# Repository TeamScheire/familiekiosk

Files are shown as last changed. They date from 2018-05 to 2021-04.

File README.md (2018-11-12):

# FamilieKiosk

__Disclaimer:__ De FamilieKiosk gebruikt [Telegram](https://web.telegram.org), en werkt dus slechts zolang de API van `Telegram` niet wijzigt en `Telegram` dit type gebruik toelaat. We doen ons best ondersteuning te bieden, maar kunnen hiertoe niet verplicht worden.

De `FamilieKiosk` is een simpele manier om verbonden zijn met familie vanop een afstand. Ideaal voor ouderen die wel op de hoogte willen zijn maar niet sociale media gebruiken.

The `FamilieKiosk` is a simple way to be connected with family from a distance. Ideal for elders who want to keep contact with family but don't use social media. 

# Nederlandse handleiding
De `FamilieKiosk` gebruikt een berichtenapp, [Telegram](https://web.telegram.org), om beelden, geluid en video door te sturen aan de FamilieKiosk-doos, welke aangesloten is op de TV. Zo zie je op de TV de berichten van je familieleden, ook al zit je niet zelf op sociale media. De FamilieKiosk-doos is wat men een IoT-device noemt. Dit betekent dat het connectie maakt met het internet via WiFi, en zo de gegevens bekomt om op de TV te tonen.

## Het toestel
Je kan zelf een FamilieKiosk bouwen, of er een bekomen via [ons](http://www.ingegno.be), via [dit formulier](https://docs.google.com/forms/d/e/1FAIpQLSeFdhst-ktf9GazYMNH7J7HR-cu2r0f12FVwysfPTQ48ZMgRQ/viewform?usp=pp_url) kan je ons gemakkelijk contacteren. Met onze handleiding ben je in een wip online berichten aan het delen! Enige technische kennis is wel vereist hiervoor!

1. Handleiding om een FamilieKiosk-doos aan je TV aan te sluiten: [FamilieKiosk Instellen](https://github.com/TeamScheire/familiekiosk/blob/master/handleiding/FamilieKiosk%20Instellen.md)
2. Handleiding om je FamilieKiosk helemaal zelf te maken: [DIY FamilieKiosk](https://github.com/TeamScheire/familiekiosk/blob/master/handleiding/DIY%20FamilieKiosk.md)

# English Manual
We are not yet active on the international market! Feel free to send us a translation.

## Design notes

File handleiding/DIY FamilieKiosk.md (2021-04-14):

# Maak zelf je eigen FamilieKiosk 

In deze handleiding leggen we uit hoe je een FamilieKiosk kunt bouwen. De Kiosk is een Raspberry Pi, welke via HDMI met je TV verbonden is.  Deze controleert output op de TV en draait een Telegram bot welke beelden, audio en video van je familieleden oppikt en afspeelt. 

## Set up Raspberry Pi
We gebruiken een Raspberry Pi 3B, welkje je bv in pakket kunt kopen bij [Velleman](https://www.velleman.eu/products/view/?id=435866)

Zo'n pakket komt met een lege microSD kaart, welke we moeten voorbereiden. We installeren er een linux OS op, zie de [software guide](https://www.raspberrypi.org/learning/software-guide/) voor meer info. Download de Raspbian Pi OS vanaf de [download pagina Raspbian](https://www.raspberrypi.org/software/operating-systems/). Gebruik de Raspberry Pi Imager, deze zal de laatste versie automatisch downloaden, waarna je een SD kaart kunt flashen. De FamilieKiosk is getest met versie.

* 2021-03-04-raspios-buster-armhf-full.zip

Eerder werden ook gebruikt:

* 2018-11-13-raspbian-stretch-full.zip
* 2020-05 raspbian

Met de Raspberry Pi Imager bekom je de laatste versie, wil je een oude versie, dan dien je de zip uit te pakken en bv [etcher.io/](https://etcher.io/) te gebruiken om de iso te flashen naar een SD kaart.

Je hebt nu je harde schijf voor je Raspberry Pi klaar. De Rasp zou moeten werken en je een linux desktop tonen. 

## Installeer nodige software op Raspberry Pi

Vooraleer je de familiekiosk zelf kan installeren moet je een aantal ondersteunende programmas installeren. Hiervoor moet je de Terminal gebruiken. Je kan de terminal opstarten met het zwarte icoon, in de menubalk links bovenaan.

Raspbian Terminal Icoon

Druk de commando's gegeven als `commando` om de nodige software te installeren. Eerst controleren we of python3 de standaard is. Voer commando uit: `python --version`. Indien het resultaat niet python 3.x versie is, maar python 2.x, dien je te switchen naar python3 via handleiding op [raspberry-valley](https://raspberry-valley.azurewebsites.net/Python-Default-Version/#switching-default-python-versions):

    python --version
    python3 --version

noteer de versies die je hebt op de RPi, bv 2.7 en 3.7, en voeg die toe aan de alternatieven (vervang XXX door de eertste twee digits van je versienummer):

    sudo update-alternatives --install /usr/bin/python python /usr/bin/python2.XXX 2
    sudo update-alternatives --install /usr/bin/python python /usr/bin/python3.XXX 1

Wijzig nu de default versie van python met

    sudo update-alternatives --config python

Test met `python --version`.

Hierna kun je de nodige software installeren

1. Beeldverwerking: `sudo apt-get install python-imaging-tk`
2. Button en buzzer support: `sudo apt-get install python-rpi.gpio python3-rpi.gpio`
3. Gstreamer voor audio en video: `sudo apt-get install python-gst-1.0 gstreamer1.0-tools`
4. telegram requirements: `sudo apt-get install libffi6 libffi-dev libssl-dev`
4. telegram python API: `sudo pip install python-telegram-bot --upgrade`
5. pexpect API: `sudo pip install pexpect`

Nu dien je de screensaver te disablen Doe dit via `sudo apt-get install xscreensaver`, dan uitzetten. Je moet eerst REBOOT doen, daarna via `Start menu->Voorkeuren->Schermbeveiliging` of indien Engelse versie via `Start menu -> Preferences -> Screensaver`. Je ziet daar een optie __Modus__, waar je uitschakelen kan kiezen als modus.

Vervolgens heb je de FamilieKiosk code nodig. Hiervoor maak je een kopie van onze code op een van volgende twee manieren. Via een clone van de code, als volgt in een terminal:

    cd
    git clone https://github.com/TeamScheire/familiekiosk.git 

of door de code te downloaden als zip van [https://github.com/TeamScheire/familiekiosk/](https://github.com/TeamScheire/familiekiosk/archive/master.zip), de zip te extracten, en op te slaan in `/home/pi`. Opgelet, hernoem de map als `familykiosk` na de unzip, dus bv indien naam map `familiekiosk-master` is:

    cd
    mv familiekiosk-master familiekiosk

Test de playback met volgende commando's in een terminal:

    omxplayer /home/pi/familiekiosk/src/video/dummy/testvideo.mp4
    gst-launch-1.0 playbin uri=file:///home/pi/familiekiosk/src/video/dummy/testvideo.mp4
    gst-launch-1.0 playbin uri=file:///home/pi/familiekiosk/src/voice/dummy/testvoice.ogg

Wanneer je foutmeldingen krijgt zoals "Pipeline doesn't want to pause." of "Pipeline wil niet pauseren" bij het uitvoeren van de laatste twee commando's, kijk dan zeker na of je het commando wel juist hebt ingevoerd. Let vooral op uri in plaats van url, het : symbool na file en de daarop volgende drie / symbolen.

## Autostart van de FamilieKiosk

Alle code is aanwezig op de Raspberry, nu moeten we nog zorgen dat het systeem automatisch de Kiosk start bij opstarten. We gebruiken `systemd` services om te autostarten.

De nodige scripts zijn aanwezig in de broncode in de map systemd, en moeten verplaatst worden naar de map `/lib/systemd/system/`. Doe dus

    sudo cp /home/pi/familiekiosk/systemd/fk_chatbot.service /lib/systemd/system/
    sudo cp /home/pi/familiekiosk/systemd/fk_tvbox.service /lib/systemd/system/

en wijzig de toegang naar 644 zodat ze kunnen opgestart worden door systemd:

    sudo chmod 644 /lib/systemd/system/fk_chatbot.service
    sudo chmod 644 /lib/systemd/system/fk_tvbox.service

Zorg nu dat deze services gekend zijn bij systemd door 1 na 1 volgende commando's uit te voeren:

    sudo systemctl daemon-reload
    sudo systemctl enable fk_chatbot.service
    sudo systemctl enable fk_tvbox.service
    sudo service fk_chatbot start
    sudo service fk_tvbox start

Op dit moment zullen deze services nog niet werken omdat je de chatbox nog niet geconfigureerd hebt! Geen zorgen, dat doen we straks.

Je kan indien gewenst de status opvragen van deze services, bv om Telegram chats te monitoren:

    systemctl status fk_chatbot.service

en voor de tvbox app:

    systemctl status fk_tvbox.service 

Indien gecrasht, herstarten kan via bv

    sudo service fk_chatbot start

of om de tvbox te herstarten:

    sudo service fk_tvbox start

Indien de tvbox niet automatisch start, zorg dan dat de Raspberry maar opstart na netwerkverbinding. Doe hiervoor:

    sudo raspi-config
    Select Option 3 (Boot Options).
    Select B2 (Wait for Network at Boot)

## Constructie van de FamilieKiosk-doos

De familiekiosk kan optioneel uitgebreid worden met drukknoppen en een buzzer. We voorzien code voor drukknop om vorige multimedia opnieuw te zien, om naar volgende multimedia te gaan, en om een antwoord/reactie te geven. Audio en video worden enkel voor een vast slot per dag getoond. De buzzer wordt gebruikt om aan te duiden dat dit slot start.

### Componenten
We gebruiken volgende componenten:

1. Een YL44 buzzer YL44 buzzer
2. Arcade drukknoppen. Bv van [arcadewinkel](https://www.bol.com/nl/p/arcadewinkel-concave-classic-arcade-drukknoppen-mixed/9200000079501752/) Drukknoppen
3. Jumper wires and connectors
4. lasercut enclosure

### Bekabeling
De Raspberry Pi 3B heeft aan de rechterkant pinnen waarop we componenten kunnen aansluiten. Deze hebben volgende nummering:

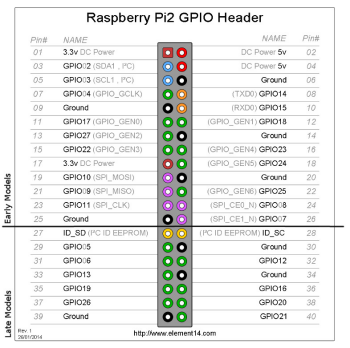
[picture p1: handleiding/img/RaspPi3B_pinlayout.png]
Rasp Pi pins


De rechterbovenhoek van deze figuur is ook de rechterbovenhoek van de Rasp Pi als je er van boven opkijkt. 

De bekabeling is als volgt: 

1. Buzzer GND pin verbinden we met een GND pin, bv pin# 05
2. Buzzer VCC pin verbinden we met de 3.3V pin, dus pin# 01
3. Buzzer I/O pin verbinden we met GPIO24, dus pin# 18
4. Alle drukknoppen zijn aan 1 kant verbonden met een GND pin, bv ook pin# 05
5. De andere kant van de drukknop gaat naar een GPIO pin. We gebruiken volgende: 
    1. Reply knop op GPIO18, dus pin# 12
    2. Next  knop op GPIO17, dus pin# 11
    3. Previous knop op GPIO23, dus pin# 16
    
Je hebt dus een stekker met 6 draden nodig. Schematisch is de bekabeling:

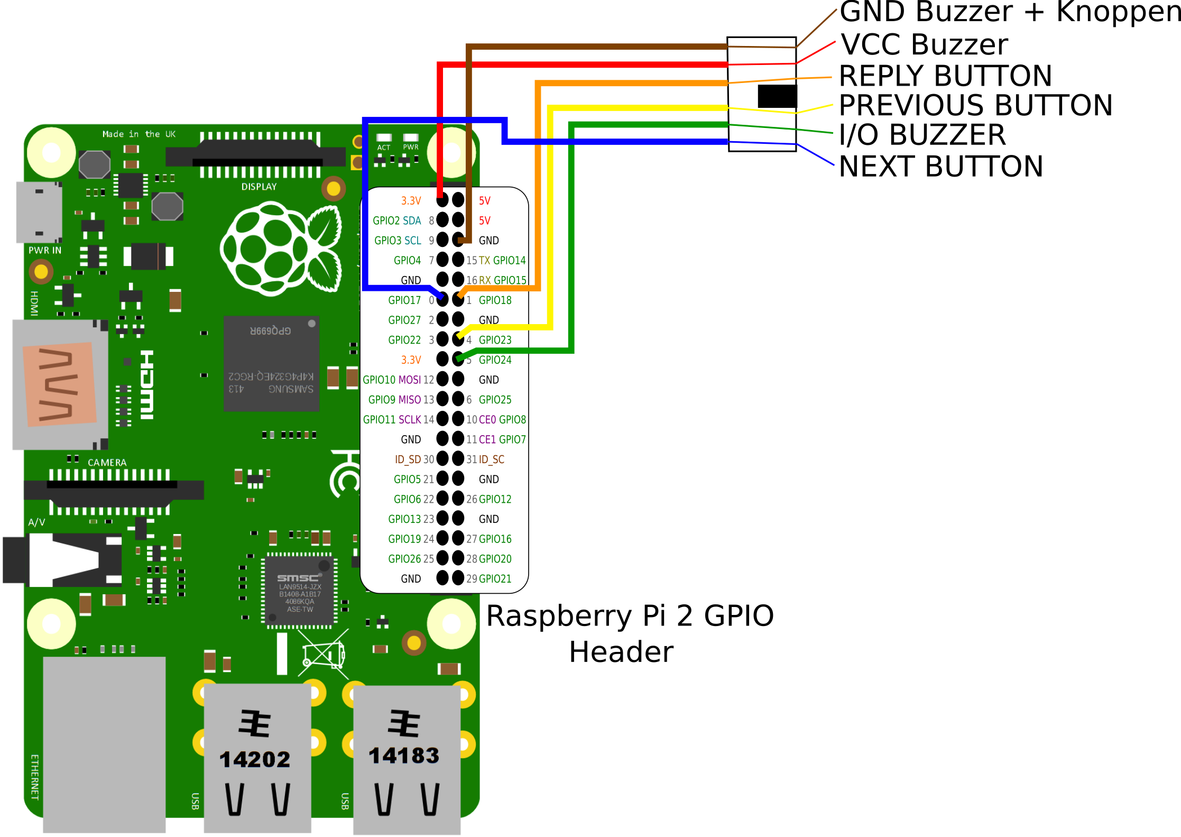
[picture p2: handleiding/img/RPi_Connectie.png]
Rasp Pi connecties


### De doos
Maak een mooie doos om de drukknoppen te bevatten, alsook de buzzer. Plaats de Raspberri Pi naast de TV, en maak een kabel naar je doos met 6 jumper wires in (GND, 3.3V, GPIO24/23/18/17). Maak kabel lang genoeg zodat doos op een gemakkelijke plek kan gezet worden.

Een voorbeeld gelasercutte doos is beschikbaar hieronder. Sla ze op als svg en pas aan naar eigen wensen:

Rasp Pi pins

In deze doos stop je de buzzer, en er is plaats voorzien voor 3 drukknoppen. De bedrading van de drukknoppen is als volgt:

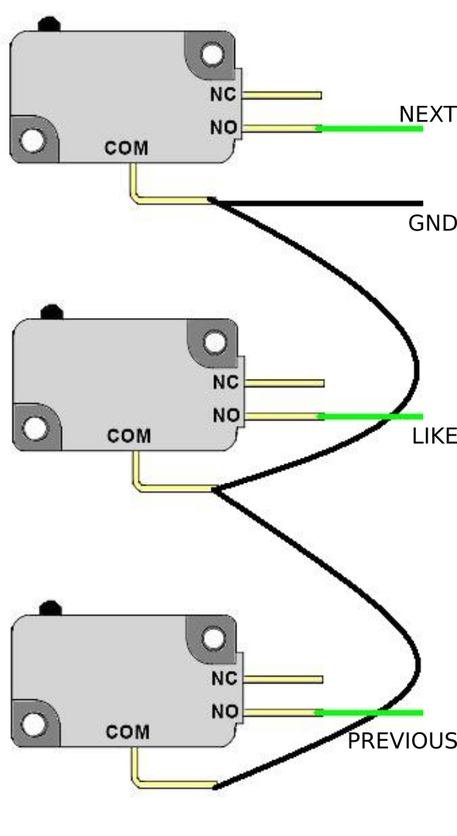
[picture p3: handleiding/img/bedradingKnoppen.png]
flexbox pushbuttons


## Instellen van de FamilieKiosk. 

De constructie en installatie is af. Dit is wat rechtstreeks van [Ingegno](http://ingegno.be/) kan bekomen worden. Nu dien je de FamilieKiosk in te stellen. Zie de [aparte installatie handleiding](https://github.com/TeamScheire/familiekiosk/blob/master/handleiding/FamilieKiosk%20Instellen.md).

## OUD: meer GPU geheugen

**Volgende is niet langer nodig voor recente Raspberry Pi OS!**

Op een Raspberry Pi 3B hebben we te weinig GPU processor kracht om video en audio te spelen met omxplayer. Om dit op te lossen doen we een wijziging in het bestand `/boot/config.txt` zoals beschreven in [hier](https://raspberrypi.stackexchange.com/questions/7716/omxplayer-doesnt-play-audio):
Open `/boot/config.txt` bv met `sudo thonny /boot/config.txt`, en voeg onderaan aan dit bestand toe:

    # sufficient gpu to run omxplayer
    gpu_mem=128

Reboot de Rasp om dit effect te laten nemen.

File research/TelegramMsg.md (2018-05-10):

# Telegram gebruiken om geluid door te sturen

We kijken eerst naar miflo project telegram backend. Dit gebruikt een ruby api voor Telegram op een server (bv een raspberry pi). Krijgt gekende berichten, parsed ze, en maakt ermee MQTT
messages naar de Arduino om zaken te doen.

Wij hebben nodig: telegram berichten opvolgen, is er geluid bij --> toelaten dat dat afgespeeld wordt. 

Onze ervaring is met python, dus kijken we naar een python api: https://python-telegram-bot.org/ 

Kunnen we hiermee geluidsfragmenten herkennen en dan afspelen via hdmi ?

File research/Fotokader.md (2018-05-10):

# Smart Fotokaders
Oorspronkelijk geen fotokaders gekocht want direct meer dan 100 eur en budget is beperkt. 
Dus, enkel info via onderzoek online. Uiteindelijk toch de Pix-Star 15 inch gekocht.

### NixPlay fotokader - 8 inch
https://www.gadgetgear.nl/2017/06/review-nixplay-cloud-frame-8-inch-digitale-fotolijst/
* Vraag is: hoe hackable is het? 
* testen?

### Frame XX 
https://www.fotolijst.info/contents/nl/d19_Digitale_Fotolijst_27_Inch.html
* Te groot
* Niet hackable
* Duur?

### Pix-Star 10.4 Inch Wi-Fi Cloud Digital Photo Frame FotoConnect XD
* Prijs is onder de 200 eur
* 10.4 in. (26.4 cm), 4:3 ratio, high-quality display with low consumption LED backlight. Manage the Frame from the Web and create a multi-frame account to remotely control up to 25 frames from 1 single web account, TOTALLY FREE.
* Send your photos by email via the 3G/Wi-Fi Network on your mobile phone, 4 GB memory (20,000 pictures), supports USB stick, SDHC and SDXC cards.Display size (diagonal): 15 inches(38.1 cm)
* Receive pictures directly on your Pix-Star frame from the Internet with its dedicated email address at NO EXTRA CHARGE
* Send pictures from your frame to individual or groups of email addresses directly from the frame
* Access more than 20 online providers and view pictures from web albums, including Picasa, Facebook, Flickr, Smugmug, and more and Receive daily updated weather forecasts for a selection of countries and cities

### Kodak Pulse digitale fotolijst
http://www.findmyorder.com/store/ekconseu/nl_NL/pd/ThemeID.3925900/PULSE_digitale_fotolijst__254%C2%A0cm_%2810_inch%29/productID.223116400
* Lijkt eenvoudig

### Braun digitale fotolijst voor Oma en Opa
https://www.fotolijst.info/contents/nl/p108_Braun_1010_Digitale_Fotolijst_WiFi.html
*  De fotolijst kan via Wifi met Internet verbonden worden en kan dan via de gratis Frameo App (Android en iOS) op afstand voorzien worden van nieuwe foto's.
*  Maak een foto met uw mobiele telefoon, selecteer de foto en stuur hem direct door naar de fotolijst.
* De digitale fotolijst stelt u één keer in op de Wifi. 
* één of meerder mobiele telefoons koppelen met de Digitale Fotolijst mogelijk via de Frameo App. 
* Meerdere telefoons kunnen verbonden worden, met één of meerder fotolijsten. De gehele familie kan dus de nieuwste foto's ontvangen. 
* De digitale fotolijst is geschikt voor microSD (max. 32 GB) geheugenkaarten. Eventuele foto's om de geheugenkaart kunnen worden overgezet naar de fotolijst, om deze snel te voorzien van enkele foto's. De microSD geheugenkaart kan als backup gebruikt worden, om alle foto's van de fotolijst veilig te stellen.

## Applicatie die werken op Tablets android
* https://www.familinq.com/ niet goedkoop, maar het lijkt mne wel een goede oplossing. Opslag in de cloud mogelijk 
* http://www.familylooped.com/about geen opslag in de cloud maar op tablet zelf, prijs niet gevonden ???

# DIY optie: 
WE PROBEREN DIT EERST, het lijkt het meest customizable en goedkoper

* Rasperry pi plus scherm, liefts TV want TV hebben ze en kennen ze
* Foto kanaal :-) 
* Applicatie Telegram
* Mogelijkheid om een audio bericht te sturen naar zender van de foto----Dit nog te bekijken hoe, want lijkt me nu niet eenvoudig met bakje van TV….
* Extra 
   * Audio berichten op bepaalde tijdstippen
   * Update van fotos op 1 tijdstip van de dag gekoppeld aan een leuke audio bericht 
   * TV? Webservice...post van de fotos

Nodig? Hdmi ingang
Usb microphone
Knop zoals die van de spelconsoles om voice message op te nemen

## DIY mogelijkheden voor fotos op TV te krijgen
Interessante dingen:

Op papier 1x maand https://neveo.io/#!/

Applicatie
https://mitene.us/en

Hoe een foto booth maken met raspberry pi
https://www.wikihow.com/Create-a-Photo-Booth-with-the-Raspberry-Pi

Flickr en raspberry pi
http://www.instructables.com/id/Internet-Photo-Frame/

Raspberry pi with lychee
https://www.pihomeserver.fr/en/2014/01/23/raspberry-pi-home-server-heberger-toutes-vos-photos/

Foto frame with raspberry pi beschreven onderaan Building a digital photo frame:

https://paulstamatiou.com/getting-started-raspberry-pi/ 

Met code voor Flickr
https://www.codeproject.com/Articles/1223258/Build-digital-photo-frame-with-a-Raspberry-Pi

https://dzone.com/articles/build-digital-photo-frame-with-a-raspberry-pi

GOOGLE PHOTO FRAME: Dit lijkt me compleet voor google fotos met applicatie photo frame van google (gevonden via https://hackaday.com/2018/03/05/shoot-and-forget-digital-photo-frame/ ), met heel wat code maar 
https://mrworf.github.io/photoframe/2018/02/26/setting-up-photoframe
https://github.com/mrworf/photoframe/blob/master/services/googlephotos.py

Good to Know:
Hoe fotos prive maken in flickr
https://www.wikihow.com/Make-Photos-Private-on-Flickr

Digital photo frame for people with dementia
http://sussexrokx.blogspot.be/2013/04/day-clock-for-people-with-dementia.html

Applicatie senior photo frame
https://play.google.com/store/apps/details?id=com.ellevsoft.seniorframe&hl=en_GB

## Gewoon foto kader kopen
15 inch, groot en heeft alles. Het zou goed zijn om te hebben en testen
https://shop.pix-star.com/products/pix-star-15-inch-cloud-frame-with-wi-fi-email-address-web-radio-and-more
In eu gevonden op amazon FR:
https://www.amazon.fr/Pix-Star-Num%C3%A9rique-FotoConnect-pouces-adresse/dp/B00MTWDG6W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

# Conclusie
* DIY kan maar problemen naar privacy (hackable, open sharen van foto’s) en replies op foto’s.  
* Daarom gekozen voor Pix-Star 15 inch fotokader om groot gebruiksgemak te hebben met beheerder van een account en emails naar een uniek adres om foto’s op fotokader te krijgen. Nu werk steken om de instellingen zo optimaal mogelijk te maken voor de noden van de zorginstelling
* Als DIY oplossing in backup is de beste optie gevonden:
https://mrworf.github.io/photoframe/2018/02/26/setting-up-photoframe
https://github.com/mrworf/photoframe/blob/master/services/googlephotos.py
Dit connecteert naar google photo’s, maar beperking is dat men enkel via queries foto’s toont of anders de laatste 5 recente foto’s

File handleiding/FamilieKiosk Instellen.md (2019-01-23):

__Disclaimer:__ De FamilieKiosk gebruikt [Telegram](https://web.telegram.org), en werkt dus slechts zolang de API van `Telegram` niet wijzigt en `Telegram` dit type gebruik toelaat. We doen ons best ondersteuning te bieden, maar kunnen hiertoe niet verplicht worden.

Je hebt een familiekiosk ontvangen. Dit omvat een doos met knoppen en een Raspberry Pi. Connecteer de delen als volgt:

1. Klik de kabel van de familiekiosk doos met knoppen aan de Raspberry Pi via de connector. 
2. Gebruik de HDMI kabel om de Raspberry Pi aan de TV te koppelen. 
3. Voor de eerste installatie moeten we nog enkele gegevens invullen. Hiertoe heb je een USB muis en toetsenbord nodig. Connecteer deze in de USB slots van de Raspberry Pi
4. De microUSB poort van de Raspberry Pi is om stroom te leveren. Plug de stroomkabel daar in, en plug deze in een stopcontact. __Opgelet: De TV moet aan zijn en de HDMI kabel ingeplugd voor je je Raspberry stroom heeft. Anders zul je geen beeld zien (Rasp start headless op).__

De Raspberry Pi start op, en toont onmiddelijk de Kiosk met de standaard foto. Om de Kiosk af te sluiten klik je op de __Linkermuis__ knop. Je bekomt dan de desktop: 

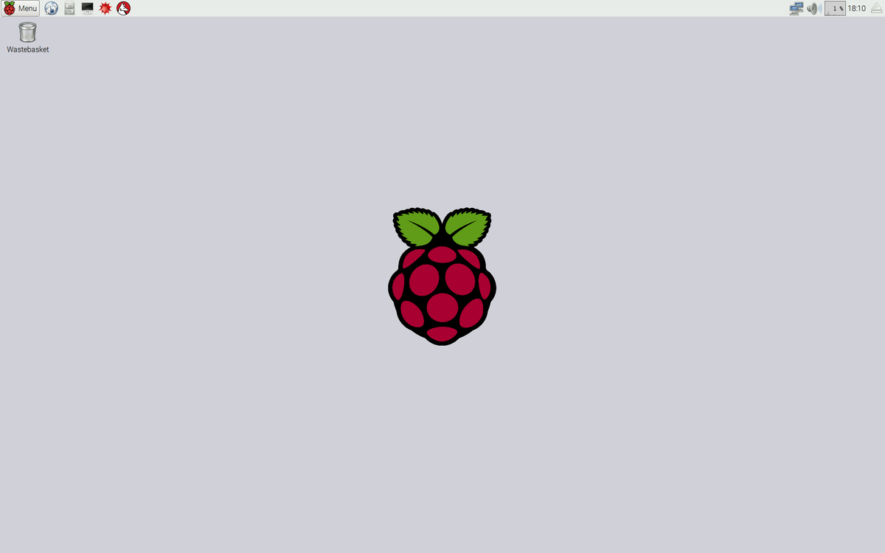
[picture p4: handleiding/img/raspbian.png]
Raspian


## Wifi Netwerk instellen

De Raspberry Pi beschikt over WiFi welke we gebruiken om met het internet te connecteren en nieuwe multimedia te bekomen voor de Kiosk. Je dient dus het netwerk in te stellen voor de locatie waar de familiekiosk opgezet wordt. Klik hiervoor in de rechterbovenhoek op het icoon van het netwerk, selecteer de SSID van je wifi netwerk, en geef je paswoord op. 

## Installeer Telegram, aamaken bot en configureren van de bot

De Kiosk werkt via een chatbot op [Telegram](https://telegram.org/) een chatapp met dezelfde functies als WhatsApp, maar met de mogelijkheid om er extra code voor te schrijven via bots. 

Net zoals bij Whatsapp, kan je via telegram groepsgesprekken hebben. De bot die je gaat maken, zal ook deel uitmaken van deze groep en de gedeelde foto's, video's en audioboodschappen automatisch kopiëren naar de familiekiosk.

1. Installeer [Telegram](https://telegram.org/) op je smartphone. 

Elke Familiekiosk moet zijn eigen _geheime_ chatbot hebben. Je gaat dus voor je eigen kiosk een chatbot aanmaken, deze configureren en toevoegen aan het groepsgesprek waar de rest van je familie in zit.

Bedenk een goede naam voor je bot, in deze handleiding gebruiken we ```MemePepeBot```. Wijzig deze door je eigen naam!

Het aanmaken en configureren van een bot gebeurt ook via Telegram door te praten met de chatbot ```@BotFather```.

Je kan dit doen via de telegram app op je smartphone, maar je kan ook via via [web.telegram.org](https://web.telegram.org) telegram openen. Voor de rest van deze handleiding gaan we er van uit dat je via de web-interface werkt.

2. Log in op [web.telegram.org](https://web.telegram.org)
3. Praat met ```@BotFather``` door te klikken op volgende link: [web.telegram.org/#/im?p=@BotFather ](https://web.telegram.org/#/im?p=@BotFather)
4. In het gesprek met ```@BotFather``` vraag je een nieuwe bot aan met volgend commando: ```/newbot``` De volledige conversatie ziet er ongeveer zo uit. Kies uiteraard een andere naam ;)

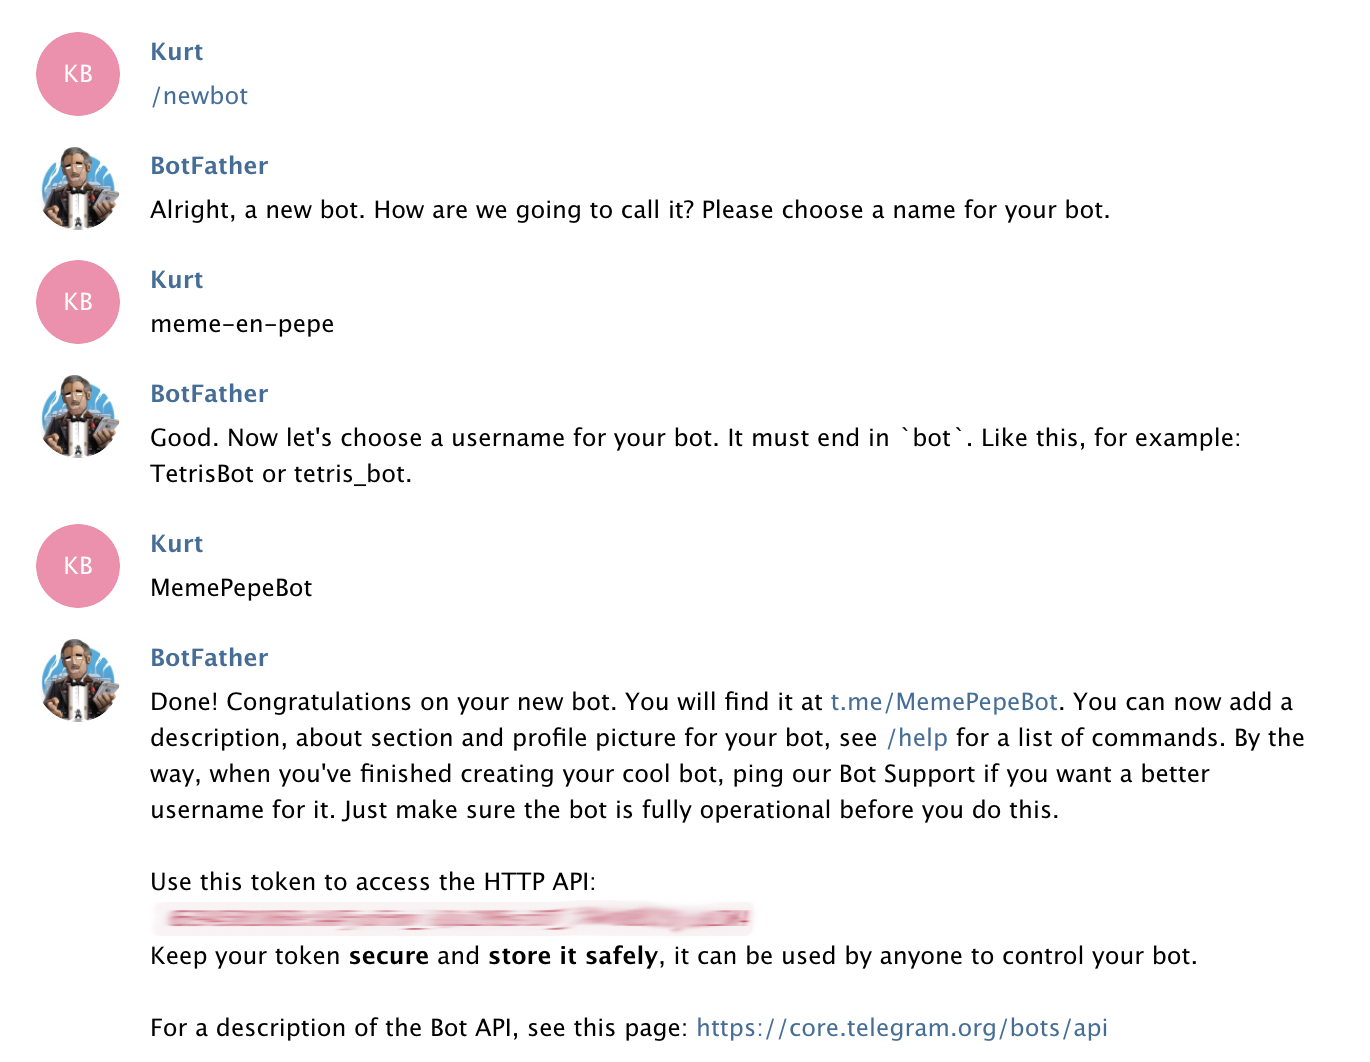
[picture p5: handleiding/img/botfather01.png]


Je hebt nu een bot gemaakt!

De token (het wachtwoord bestaande uit de rode letters en cijfers) kopiëer je en hou je even bij. Je hebt dit straks nodig in het configuratiebestand van de familiekiosk applicatie. Hou het voor de rest zeker geheim en geef het aan niemand anders door.

Een volgendestap is nodig om je bot de mogelijkheid te geven om te luisteren naar alles wat er gezegd wordt in een chatgroep en niet alleen de commando's (die beginnen met een /).

5. Geef volgende commandoreeks één voor één in (of je kiest een antwoord na het eerste commando via de keuzeknoppen die @BotFather aanbiedt)

```
/setprivacy
@MemePepeBot
disable
```

De conversatie ziet er dan ongeveer als volgt uit:

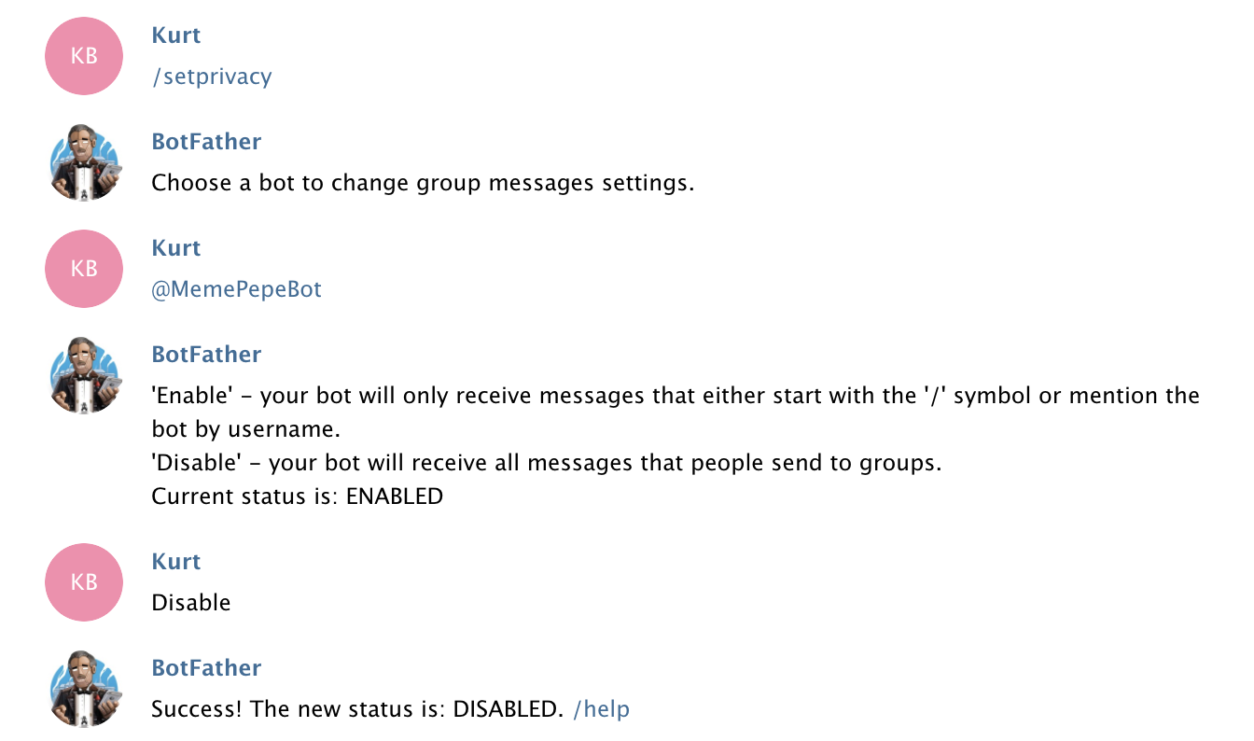
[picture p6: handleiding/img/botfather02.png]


Als laatste stap moet je de bot toevoegen aan de chatgroep waar de rest van de familie ook in kan komen (of al in zit).

6. Voeg deze bot toe aan de chatgroep, net zoals je elke andere gebruiker van Telegram zou toevoegen.

## Familie Kiosk instellen

De configuratie van de Kiosk is in bestand `/home/pi/familiekiosk/src/config.py`. Maak dit bestand aan door het basisbestand te kopieren. Je kan bestand `/home/pi/familiekiosk/src/config.py.in` openen met tekstverwerker `thonny` en opslaan als `config.py` in dezelfde map, of start een Terminal en gebruik de commando's:

	cp /home/pi/familiekiosk/src/config.py.in /home/pi/familiekiosk/src/config.py
	thonny /home/pi/familiekiosk/src/config.py

Bovenaan dit bestand moet je het __TOKEN__ van je chatbot geven, en een paswoord instellen van de chatbot:

	# the token of your bot obtained from Telegram
	TOKEN = "YOUR_TELEGRAM_BOT_TOKEN"
	# the password required to listen to the chatgroup
	PASSWORD = "FK_TEST"

Wijzig ```FK_TEST``` in een _goed_ paswoord! Iedereen die dirt wachtwoord kent, zal foto's kunnen sturen naar je kiosk kan sturen. Omdat in principe iedereen over heel de wereld met de bot zou kunnen praten, is deze extra beveiliging ingebouwd.

De andere opties die je mogelijks wil wijzigen zijn:

1. Als geen knoppen, wijzig dan de knop van ```True``` naar ```False``` 
2. Als geen buzzer, wijzig dan ```BUZZER_PRESENT``` in ```False```
3. De tijd van het alarm staat op 18u. Dan zal voor 30 min de meest recente foto's, audio en video getoond worden. Om ander uur te kiezen, wijzig dit:
```
	ALARM_HOUR = 18
	ALARM_MIN = 0
```

Je kan nu de Raspberry Pi herstarten om de kiosk op te starten met de chatbot. 

## Berichten sturen naar de Kiosk
Om berichten te sturen, voeg je jouw gemaakte chatbot, hier ```MemePepeBot``` genoemd, toe aan een groep, of doe je er een rechtstreeks gesprek mee. Voordat de bot je berichten zal doorsturen naar de kiosk, moet je wel een keer het wachtwoord doorgeven. Doe dit als volgt:

1. zoek op je chatbot en voeg hem toe

Chatbot zoeken

2. test of de chatbox aan staat. Dit is het geval als de Raspberry Pi opgestart is. Indien niet, laat weten aan de eigenaar hem opnieuw in het stopcontact te steken! Je kan dit testen via het start commando in de chat waarop de chatbox met _Hi_ zal antwoorden:
```
	/start
```
3. Geef nu het paswoord via het __/secret__ commando, gevolgd door het paswoord welke je gekozen hebt. Hierna zal elke chat met multimedia een antwoord krijgen van de chatbot om aan te duiden dat die goed ontvangen werd
```
	/secret XXXXX_JOUW_GEHEIM_PASWOORD
````

Test nu de chatbot door een foto te sturen, of een video, of een audiofragment. Zie telegram documentie hoe dit te doen indien de interface niet duidelijk is.

## Beperkingen

1. Vooraleer de tvbox update en de __Next__ en __Previous__ knoppen werken moeten er twee foto's aanwezig zijn bij het opstarten. Bij slechts 1 foto blijft steeds die ene foto te zien. Bug [#1](https://github.com/TeamScheire/familiekiosk/issues/1)
2. Een kabel is nodig van de knoppenbox naar de Raspberry Pi bij de TV, kan dat niet zonder? Ja. Dan moet bv een nodeMCU en een batterij in de knoppenbox gestopt worden en via WiFi of bluetooth of IR gewerkt worden. Patches welkom, maar moet wel __eenvoudig__ blijven: connectie semi automatisch, batterij vervangen eenvoudig, ...

## Startfoto's opladen
Het is niet nodig startfoto's op te laden, maar wel handig dat de Kiosk iets heeft om te tonen van bij het begin. Startfoto's kun je op een usb stick plaatsen. Ze dienen extensie `.jpg` te hebben. Niets anders wordt aanvaard! 

Stop de usb stick in de Raspberry Pi, en copieer de foto's naar de map `/home/pi/familiekiosk/src/pics`. Deze foto's zullen getoond worden door de Kiosk. Opgelet, elke foto wordt enige tijd getoond. Zet dus ook niet teveel foto's op.

## Ruimte vrijmaken
Indien veel foto's, video's of audio naar de Kiosk gestuurd wordt, zal het nodig zijn na verloop van tijd ruimte vrij te maken. Connecteer een muis en toetsenbord aan de Raspberry Pi, en klik de linkermuisknop om de Kiosk te stoppen. 

Start de bestandenbeheerder vanuit de top menubalk, en verwijder de oudste multimedia bestanden uit de mappen

	/home/pi/familiekiosk/src/pics
	/home/pi/familiekiosk/src/video
	/home/pi/familiekiosk/src/voice
	
Je kan de multimedia verwijderen of op een stick plaatsen als backup. Opgelet, bij verwijderen, vergeet ook niet de vuilnisemmer (Wastebasket) te legen. Herstart de Raspberry hierna om de Kiosk terug te starten.

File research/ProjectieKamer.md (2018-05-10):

# Projectie van de familieleden in 3D

We willen pogen de kamer/tuin van de familieleden bij de zorgbehoevende te brengen. De familieleden nemen op met 360 graden camera.
We projecteren dat in een ruimte

## test Qantic en youtube
We nemen video op met een Qantic, live streamen dat op youtube, en projecteren dit. 

Probleem: youtube heeft geen controle op de hoek die je kunt afspelen, enige controle die er is via een eigen youtube player: 
https://developers.google.com/youtube/iframe_api_reference#Playback_controls

Je moet dus zelf eerst beeld juist projecteren. 
Dit kunnen is een feature request bij google al voor meedere jaren: https://issuetracker.google.com/issues/35176822

Dit wordt getest.

Met Rasp Pi crasht chromium op 360 video. We testen vivaldi en firefox-esr (enable source packages in apt/sources.list)
Vivaldi kan ook geen 360 graden spelen op youtube, crasht wel niet. Firefox crasht niet maar de video speel
veel te traag en met te weinig frames

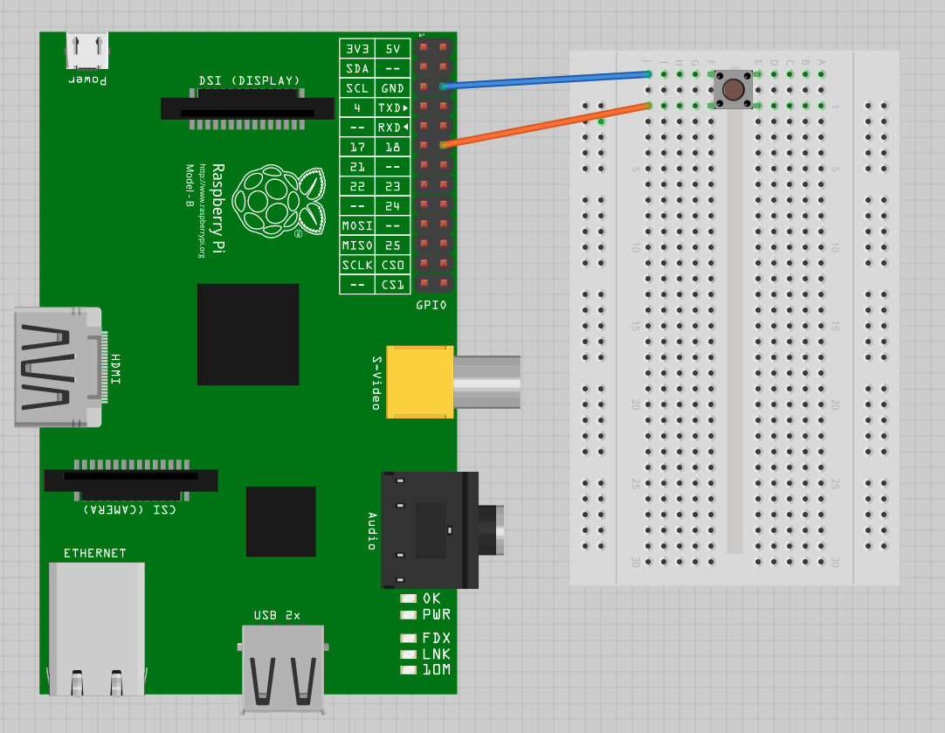
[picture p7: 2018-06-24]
handleiding/img/RaspPi3B_btn.png

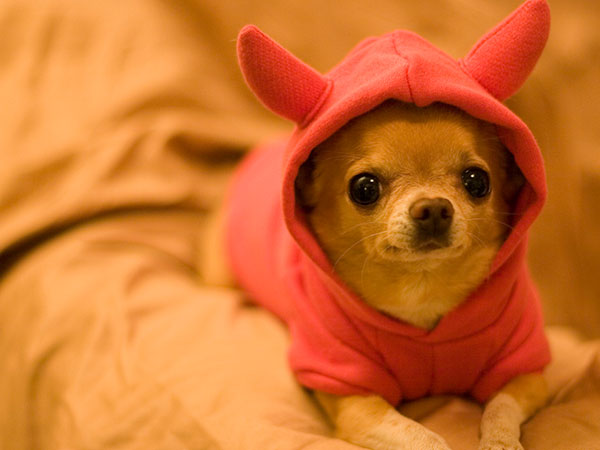
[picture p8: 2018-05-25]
src/pics/dummy/dummy.jpg

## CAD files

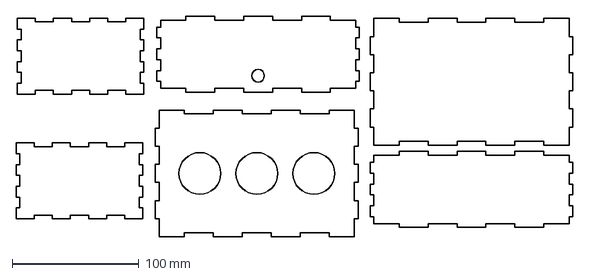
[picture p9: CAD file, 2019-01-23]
lasercut/alternative/familiekiosk-remote.dxf
439.4 x 174.1 mm

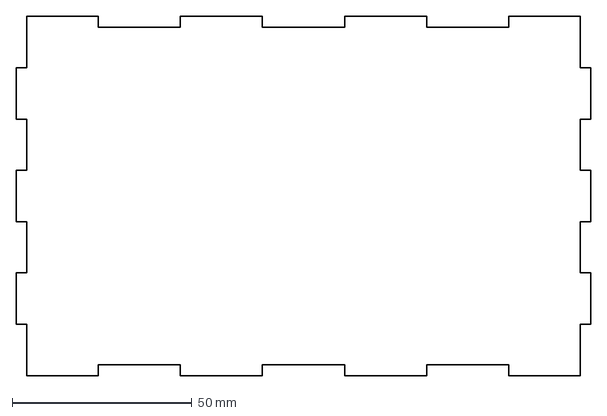
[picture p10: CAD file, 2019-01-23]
lasercut/alternative/export-bottom.dxf
160.0 x 100.0 mm

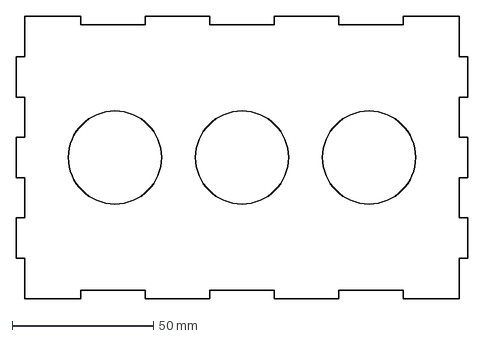
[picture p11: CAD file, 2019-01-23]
lasercut/alternative/export-top.dxf
160.0 x 100.0 mm

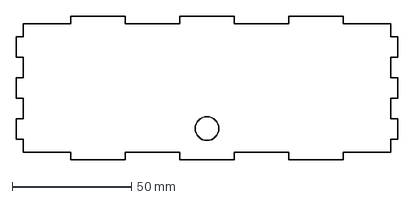
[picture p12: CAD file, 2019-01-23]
lasercut/alternative/export-back.dxf
160.0 x 60.0 mm

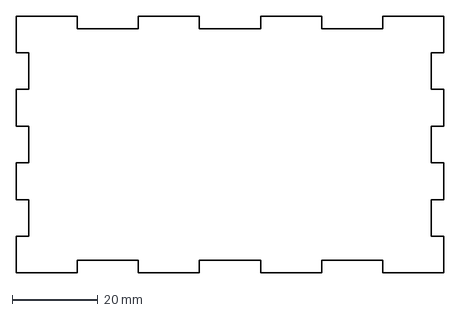
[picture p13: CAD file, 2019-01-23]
lasercut/alternative/export-right.dxf
100.0 x 60.0 mm

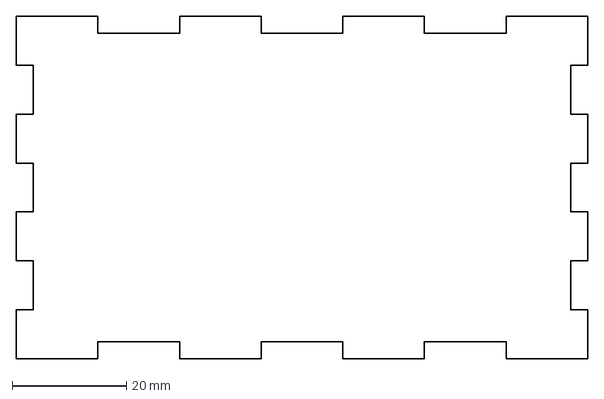
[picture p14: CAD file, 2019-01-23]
lasercut/alternative/export-left.dxf
100.0 x 60.0 mm

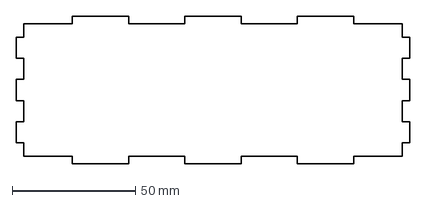
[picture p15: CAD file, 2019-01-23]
lasercut/alternative/export-front.dxf
160.0 x 60.0 mm

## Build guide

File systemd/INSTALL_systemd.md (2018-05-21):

Use systemd to autostart the familykiosk

The given systemd services must be stored in

    /lib/systemd/system/

so do:

    sudo cp fk_mariabot.service /lib/systemd/system/
    sudo cp fk_tvbox.service /lib/systemd/system/

and set the correct permissions (644)

    sudo chmod 644 /lib/systemd/system/fk_mariabot.service
    sudo chmod 644 /lib/systemd/system/fk_tvbox.service

Now make sure the service starts:

    sudo systemctl daemon-reload
    sudo systemctl enable fk_mariabot.service
    sudo systemctl enable fk_tvbox.service

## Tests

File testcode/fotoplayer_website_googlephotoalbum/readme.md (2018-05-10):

Based partially on https://paulstamatiou.com/getting-started-raspberry-pi/#piframe

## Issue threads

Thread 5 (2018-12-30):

Automatisch (her-)connecteren met TelenetWiFree en/of Telenet Homespot

bram-atmire, 2018-12-30:
Situatie: een familielid die de Familiekiosk gebruikt heeft geen eigen internetverbinding. We gebruiken de wifi module op de raspberry pi om connectie te maken met een Telenet hotspot in het appartementsgebouw & loggen in met onze eigen account gegevens daar.

Het probleem is dat er een timeout op dit soort sessies zit, waarna het dan opnieuw nodig is om naar een webbrowser te gaan en opnieuw in te loggen.

Mogelijk is dit out of scope voor de familiekiosk zelf, maar als hier een manier is om dit "opnieuw inloggen" te automatiseren en op te nemen in de documentatie, zou dat wel mooi meegenomen zijn.

bmcage, 2018-12-31:
Vrees dat zoiets aan Telenet zou moeten gevraagd worden. Zij hebben er natuurlijk geen baat bij dat iemand zijn verbinding gebruikt bij iemand anders als een permanente oplossing. In dat geval zullen ze willen dat je klant wordt op die residentie...

bram-atmire, 2018-12-31:
Ik heb al mogelijk een halve oplossing: Telenet Wifree gaat blijkbaar via login op niveau van het netwerk/ssid, terwijl homespot via de browser gaat. We gaan eens experimenteren met Wifree om te zien of dat automatisch opnieuw kan verbinden.

kavans2, 2019-05-05:
Is hier al een oplossing voor gevonden? Surfen via Telenet Homespot heeft als nadeel dat het datavolume meegerekend wordt bij het datavolume van de account waarmee je inlogt.  Wifree heeft als nadeel dat het aantal gebruikers beperkt wordt (omwille van performantie redenen).  Komt daarbij dat het publieke IP adres van de raspberry wifi typisch om de 24u wijzigt, waardoor raspberry "clients" hun "server" niet meer vinden.  Een tussen oplossing zou kunnen zijn om zelf een wireless router te installeren, die (aan de Internet kant) inlogt op Homespot of Wifree.  Dan deze wireless router aan de private kant zo configureren dat de raspberry en zijn clients steeds een vast IP adres krijgen.  Of gewoon DHCP disablen en een IP adres hard coderen op de raspberry zelf.

oneindelijk, 2019-07-29:
Je kan dit inderdaad, configureer de wpa_supplicant om met het volgende config stukje te werken:
network={
        ssid="TelenetWiFree"
        scan_ssid=1
        key_mgmt=WPA-EAP IEEE8021X
        eap=TTLS
        identity="USER.NAME@telenet.be"
        password="TELENETPASWOORD"
        phase2="auth-MSCHAPV2"
}
indien je de wpa_supplicant service opstart met de wpa_supplicant@[interface], waarbij [interface] doorgaans wlan0 is op een raspberry, is de config file /etc/wpa_supplicant/wpa_supplicant-[interface].conf

mhindery, 2021-06-08:
@oneindelijk het lukt mij met bovenstaande settings niet om te verbinden met TelenetWifree op een RPi4. Heb je toevallig een werkend updated config?

bmcage, 2021-06-10:
@mhindery het werkte wel met RPi3 ??
Ik zou zeggen, via de Desktop login doen, onthoud hij normaal, zie mogelijke settings in
https://www.netweters.be/t5/Instellingen-software-hardware/Wifree-onder-linux/td-p/28615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

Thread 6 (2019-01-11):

video's worden niet getoond

janvangent, 2019-01-11:
Video's die per telegram naar de raspberry pi verstuurd worden verschijnen niet in de foto loop.
Op dit moment heb ik nog geen volgende/vorige knoppen. Is het mogelijk om de video's ook gewoon in de loop te laten afspelen (tussen de foto's door?)

bmcage, 2019-01-12:
Video's worden enkel getoond tijdens alarm tijd. Daarbuiten enkel de foto's.
Alarm tijd kun je in stellen in je `config.py`. Als je kijkt naar voorbeeld
[config.py](https://github.com/TeamScheire/familiekiosk/blob/master/src/config.py.in)
daar alarm tijdstip aanpassen.

Alarm tijd duurt nu 30 min. Je zou dat langer kunnen maken in https://github.com/TeamScheire/familiekiosk/blob/master/src/FK_TVbox.py#L213 door die lijn bv  +200 ipv +30 te zetten. Opgelet, wel zorgen dat je niet voorbij middernacht gaat, dat zou extra code vereisen.

Echt alles tonen zoals het binnenkomt in volgorde (audio, pic en video) zou een herwerken van de code vereisen. We wilden niet hebben dat er geluid was, dan weer niet, dan wel. We opteerden voor een vast tijdstip om je op de kiosk te richten om alle recente zaken te zien. Ideaal op moment dat er in kamer gegeten wordt bevoorbeeld en verpleegster passeert. Daarom 18u.
Mijn ervaring met fotokaders is dat je na enige tijd 200 foto's hebt. Die 20 sec tonen (instelbaar met `SHOW_JPG_SEC` in `config.py`)  is al een uur foto's. Dat is dan lang wachten op eens de nieuwe. Daarom op alarm tijd alle nieuwe berichten.

bmcage, 2020-05-20:
Zoals gemeld, momenteel geen plannen om deze optie toe te voegen

Closed 2020-05-20.

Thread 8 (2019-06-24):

pictures from previous day not picked up

OridanDesta, 2019-06-24:
When the kiosk (RaspberryPi) is switched off in the evening, and pictures are sent to the kiosk that same evening. The pictures don't get pickud up the next day when the kiosk (RaspberryPi) is switched on again.

bmcage, 2019-06-24:
Normally Telegram sends the pictures through when the bot connects again. At least this used to be the case.
Has it always been like that for you ? The bot autostarts, and after start again receives new pics?

bmcage, 2019-06-24:
You are sure not two bots are active, so telegram is sending it somewhere, just not the bot that is down at that time ?

OridanDesta, 2019-06-25:
When the bot connects again, Only the pictures from that day are picked up. Not the ones from the previous day, for example

Day 1
17:00 bot is functional and picks up pictures
22:00 bot is switched OFF
22:05 picture A sent in Telegram
DAY2
07:00 picture B sent in Telegram
08:00 bot is switched ON
08:00 bot picks-up picture B but NOT picture A

But from your answer I can assume the problem is at telegram and not in the bot?

bmcage, 2019-06-25:
I never tested with waiting so long. You receive picture B while bot was off, so this could be how telegram functions, if too long ago, purge it.
Is it needed to switch off the raspberry for you? It is low energy device. Switching off monitor/tv is the important one.

OridanDesta, 2019-06-25:
Unfortunately we can't get grandma to understand to leave the raspberry pi on all the time.
But we'll try a workaround by defining timeframes together with her. and a time-programmable power-adapter

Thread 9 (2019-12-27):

Problem with chatbox service on startup

janvangent, 2019-12-27:
Today I had to make a fresh install of raspbian (latest version, istalled by using the NOOBS installer).
Last time I didn't have this issues, but now it seems impossible to get the fk_chatbox to startup automatically when the raspberry pi is booted. I followed (and repeated multiple times) the procedure explained in the manual.
The files are in the systemd/system folder, they have been chmod'ed, and i ran these commands (sequentially):
sudo systemctl daemon-reload
sudo systemctl enable fk_chatbot.service
sudo systemctl enable fk_tvbox.service
sudo service fk_chatbot start
sudo service fk_tvbox start

Any further suggestions?

When the system boots, the raspberry does display the pictures automatically, but the chatbox doesn't start on startup....

bmcage, 2019-12-29:
I don't have a setup with latest raspbian yet, so no way to test yet.
Don't see specific systemd changes for raspbian 10 over the previous 9.
Any output on

    systemctl status fk_chatbot.service

Normally if there was an error this should show what the error was

janvangent, 2020-01-02:
fk_chatbot.service - Telegram Family Chat Bot
   Loaded: loaded (/lib/systemd/system/fk_chatbot.service; enabled; vendor preset: enabled)
   Active: failed (Result: exit-code) since Fri 2019-12-27 22:41:14 CET; 5 days ago
  Process: 655 ExecStart=/usr/bin/python /home/pi/familiekiosk/src/FK_ChatBot.py > /home/pi/familiekiosk/output_chatbot.log 2>&1 (code=exited, status=1/FAILURE)
 Main PID: 655 (code=exited, status=1/FAILURE)

dec 27 22:41:14 raspberrypi python[655]:     result = func(self, *args, **kwargs)
dec 27 22:41:14 raspberrypi python[655]:   File "/usr/local/lib/python2.7/dist-packages/telegram/bot.py", line 199, in get_me
dec 27 22:41:14 raspberrypi python[655]:     result = self._request.get(url, timeout=timeout)
dec 27 22:41:14 raspberrypi python[655]:   File "/usr/local/lib/python2.7/dist-packages/telegram/utils/request.py", line 270, in get
dec 27 22:41:14 raspberrypi python[655]:     result = self._request_wrapper('GET', url, **urlopen_kwargs)
dec 27 22:41:14 raspberrypi python[655]:   File "/usr/local/lib/python2.7/dist-packages/telegram/utils/request.py", line 224, in _request_wrapper
dec 27 22:41:14 raspberrypi python[655]:     raise NetworkError('urllib3 HTTPError {0}'.format(error))
dec 27 22:41:14 raspberrypi python[655]: telegram.error.NetworkError: urllib3 HTTPError HTTPSConnectionPool(host='api.telegram.org', port=443): Max retries exceeded with url: /bot633247387:AAFxAxfnSj7UK1Z
dec 27 22:41:14 raspberrypi systemd[1]: fk_chatbot.service: Main process exited, code=exited, status=1/FAILURE
dec 27 22:41:14 raspberrypi systemd[1]: fk_chatbot.service: Failed with result 'exit-code'.

janvangent, 2020-01-02:
After a reboot, when I check the status of the service I get the message above.
If afterwards I start it manually by entering

> sudo service fk_chatbot start
It starts, and when I check the status of the service it is running succesfully.

Any ideas?

janvangent, 2020-01-02:
OK now it works.
What I did:
Run sudo raspi-config .
Select Option 3 (Boot Options).
Select B2 (Wait for Network at Boot).

I believe systemd was trying to run the service, before the wifi connection was active, resulting in a failed attempt/error.
Now it waits during boot until network connection is active.

bmcage, 2020-01-03:
Great. The install md files to update with this. You fancy a PR for that?

I see also it was made for Python 2.7, which now is deprecated. Normally code should work with python 3 too though. As raspbian 10 still ships python2.7, we can worry about it later though.

bmcage, 2020-05-20:
Dit gedocumenteerd in de documentatie nu, zie
[FamilieKiosk.md](https://github.com/TeamScheire/familiekiosk/blob/master/handleiding/DIY%20FamilieKiosk.md)

Closed 2020-05-20.

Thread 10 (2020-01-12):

whatsapp heeft nu ook api

kurtbeheydt, 2020-01-12:
Via Twilio, nog in beta momenteel en betalend: https://www.twilio.com/whatsapp/pricing/be
Maar 0,005 euro/ontvangen sms is wel niet zo duur denk ik. Als je het aantal berichtjes terug beperkt ;)

Misschien interessant om eens te bekijken? Ik merk dat telegram voor sommigen toch nog een drempel is.

bmcage, 2020-01-13:
Ik heb geen watsapp :-) Niet direct duidelijk of foto/voice werkt

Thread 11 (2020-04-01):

Camera voorziening

bartcerneels, 2020-04-01:
In tijden van corona lockdown is het onmogelijk om gebruikers op te zoeken in woonzorg centra.

Met een camera kan live chat en opname van video toegevoegd worden.

Kan ook gebruikt worden in ziekenhuizen, elke kamer is voorzien van een TV, zelfs 1 per bed.

Zelfs iemands laatste moment zou opgenomen kunnen worden... Gestart door verpleging.

Een idee van [CoronaDenktank #corona-afscheid](https://makeinbelgium.slack.com/archives/C0107MMAJ0K).

bmcage, 2020-04-02:
Rasp Pi camera's zijn goed ondersteund, dus mogelijk. Naar privacy en hacken is het wel wat moeilijker, gezien bediening voor ouderen eenvoudig moet blijven.
Een lichtje als camera aan is bevoorbeeld als indicate, ...

bartcerneels, 2020-04-02:
> Een lichtje als camera aan is bevoorbeeld als indicate, ...

Ik zou zelfs een full LED ring rond de camera bouwen, niet enkel voor indicatie maar ook belichting.

bartcerneels, 2020-04-02:
Een microphone array zal misschien ook nodig zijn: http://wiki.seeedstudio.com/ReSpeaker_4-Mic_Linear_Array_Kit_for_Raspberry_Pi/

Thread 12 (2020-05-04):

Problem after clean install

janvangent, 2020-05-04:
Hi all,

Just did a clean install of raspbian-buster on a Raspberry Pi 3 A+
I have done 2 installs on older raspbian images, both on Pi 3 B without issues, so this is new to me. Any suggestions?
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

Best regards,
Jan

janvangent, 2020-05-07:
Today I've done a clean install with raspbian stretch instead of the new Buster.
Exact same problem.

I've tried switcing to Python 3.7 (systemwide), which results in a failed status as well, but with slightly different errors.

bmcage, 2020-05-08:
dtm.timezone no longer exists it seems ...
this is part of the telegram library, so error is there.
Cannot test at the moment, I suppose you did:

    sudo pip install python-telegram-bot --upgrade  ??

perhaps pip3 on buster instead of pip ? I see in the telegram code

    import datetime as dtm  # dtm = "DateTime Module"

expecting to have timezone is this line: https://github.com/python-telegram-bot/python-telegram-bot/blob/master/telegram/utils/helpers.py#L82

This seems to contain how to fix: https://github.com/python-telegram-bot/python-telegram-bot/pull/1506/files/cc40d63a8ca2e51f71e690fe491cb9d4d31a06d4
and seems to indicate you MUST use python 3.3+ to have dtm.timezone.

So, if not using 3.3+ you need an older version of  python-telegram-bot, but this might not work with current telegram api. Otherwise, use python 3.7, and let's fix the errors due to that. Seems the best way forward. Post python 3.7 error in new bug thread

bmcage, 2020-05-20:
Is this fixed #7 with merged?

janvangent, 2020-05-25:
Yep! #7 fixed this.

Sn1ckerson, 2020-06-01:
Did a clean install, updated Python (3.7) and followed all the steps from the manual (with the new files on this github). Got the same error. Do I have to change some lines of code myself or should this be fixed?

janvangent, 2020-06-01:
Did you check which Python is being used (systemwide)? After a python install, it is not necessary being used...

Sn1ckerson, 2020-06-02:
When I type the command
`$ python3 --V `
it says 3.7
However this got me thinking, why is this saying python3 and not just python.
So I checked
'$ python --version'
and it still said 2.7.6.5 or something.

So then i recalled the tutorial that I followed told me to go in the bashrc file and type alias python3 = 3.7 instead of python = 3.7
Changed it and now it's actually using 3.7.

After reboot ran the commands
'sudo systemctl daemon-reload
sudo systemctl enable fk_chatbot.service
sudo systemctl enable fk_tvbox.service
sudo service fk_chatbot start
sudo service fk_tvbox start
systemctl status fk_chatbot.service'

And... same attributeError: 'module' has no attribute 'timezone'
Is this because I ran all the previous commands when I apperantly still had python 2.7 running?

ErwinP, 2020-06-08:
Hi Sn1ckerson,

Sorry it took a while to get back to you.

What happens if you manually run FK_ChatBot.py by running the following code from the terminal:
```
cd /home/pi/familiekiosk/src/
python FK_ChatBot.py
```

Furthermore, which bashrc file did you modify? By addingthat alias to the `home/pi/.bashrc` (or `~/.bashrc`), or did you add it in `/etc/bash.bashrc`? Note that only the latter allows for a system wide switch to python3, whilst modifying the former will only switch the user 'pi' to Python3. And as I believe that the service is started by the system, it will not working if only 'pi' is on python3.

Regards,
Erwin

Sn1ckerson, 2020-06-14:
Hi Erwin

Thank you for the reply. I did add the alias to the first one so I did the following:
First checked the code you gave me, this is the reply:

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

Next I added the alias using code:
`sudo nano /etc/bash.bashrc`
Window pops up that says GNU nano 3.2, bunch of blue text
I wrote this on the first line:
`alias python='python3.7'`
ctrl+X saved it with the same username and exit
Did a reboot, reran the FK_ChatBot.py, same error.

In another thread you asked me what it said when I type
`$ python -m telegram`
>/usr/local/bin/python3.7: No module named telegram
I'm looking at this and am thinking, is this because it's looking in the bin/python3.7 folder, which didn't exist when I installed telegram?

Now I really want it to get it to work, just out of pure stubbornness.

Kind regards
Nick

ErwinP, 2020-06-14:
Hi Nick,

I have reasons to believe you're almost there!

You installed the python telegram API previously, but only for python 2.7, as that was your default python version at that time.

Since modules for python2 do not get recognized by python 3, you have to install that module again. That is also what the error is saying: python doesn't know what you mean with 'telegram'.

Now that you are on python3 system wide, you can run the following (taken from the installation manual):

sudo pip install python-telegram-bot --upgrade

sudo pip install pexpect --upgrade

This will install the required modules for python3.

After you've did this, you should be able to run the FK_Chatbox.py without rebooting. If you don't get an error, you can reboot, and the service should be running. If it does give an error, you can post that output here ;-)

Kind regards,
Erwin

bmcage, 2020-06-14:
As @ErwinP says.
pip will only do the trick if it calls python3, which should be the case with your bashrc change. If not, use pip3 as command to be sure

Sn1ckerson, 2020-06-15:
Using pip gave me a bunch of "Requirements already satisfied" text.
Using pip3 did a new install.
Reran the python FK_ChatBot.py command and.... ModuleNotFoundError:No module named 'telegram'...

Sn1ckerson, 2020-06-15:
Did some more digging, When I open the FK_ChatBot.py file it says Python 3.7.3 (/usr/bin/python3) in the "shell" box on the bottom.
When I explore the usr/bin folder, there's no python3 map, I do have 3 python folders in the usr/lib folder: python 2.7, python3 and python 3.7, the python3 map only has the dist-packages folder inside of it, the others are stacked with a bunch of folders. When I used the `install python telegram` code it refers to the python 2.7 (pip) or python 3.7 (pip3) folders, with exception for:
> Requirement already satisfied, skipping upgrade: certifi in /usr/lib/python3/dist-packages (from python-telegram-bot) (2018.8.24)

Starting to think I made it too messy and should just do a clean install again.. I did a clean install from the rasberrypi website a couple of weeks ago yet it still had python 2.7 on it? Where do I get the one that has 3.7 already in it?

bmcage, 2020-06-15:
python 3.7 is always in now. python 2 is end of life
I used Raspberry Pi OS (32-bit) with desktop and recommended software (may 2020), and then directly after install on the SD card and startup:

    sudo apt update
    sudo apt dist-upgrade

Then if `python` does not start a python 3.7 shell, to change python version over the default one: https://raspberry-valley.azurewebsites.net/Python-Default-Version/#switching-default-python-versions

I never did changes in the my bashrc for that, as that seems like something that would be for one user only, and part of familiekiosk is launched at startup, not as that user.

For telegram, pip3 install should work, but probably there is a package in debian now: https://ubuntu.pkgs.org/20.04/ubuntu-universe-i386/python3-python-telegram-bot_12.4.2-1_all.deb.html
If that is the case, just try

    sudo apt install python3-python-telegram-bot

instead of the pip3 install of the bot api. Note that pip3 packages sometimes start with python3 instead of with python, for the python 3 version. It's on my todo to test and update the manual, sorry.
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
bmcage, 2020-06-17:
ok, updated manual.
Your last error was an error due to the pull request, import os was no longer at the top. Fixed in current version, do git pull, or overwrite with latest version here in repo of `src/FK_TVbox.py`.  Please test. This means other errors might be present too, as everybody using latest code should have had this issue ...

Sn1ckerson, 2020-06-20:
Running it now gives the fellowing error:
Jun 20 13:15:42 raspberrypi python[1741]: No valid config file found - did you rename config.py.in to config.py?
Which is strange because the file in src is called config.py.in

bmcage, 2020-06-22:
You need to indeed rename config.py.in to config.py, and open it, setting the configuration options as you want them. Like your channel and token acces to Telegram:

https://github.com/TeamScheire/familiekiosk/blob/master/handleiding/FamilieKiosk%20Instellen.md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

The systemctl still says: No valid config file found, so set that first.

Sn1ckerson, 2020-07-07:
Hi, sorry it took a while. Tried to rush things, SD-card got broken (3d-printed box was too small..)
Good news! I'm currently looking at the photo's I uploaded on my TV and I'm able to scroll through them (somewhat).
A few issues however:

1. Both FK_chatbot and TVbox don't start errorless after reboot. They do start but nothing is showing, so I checked the status of both programs and got the "config.py file not found" error for both of them. Strange because it's there. Same thing when I try to start it through the terminal with `sudo service fk_tvbox start`.
But when I start it manually by going to the familiekiosk/src files, it works. Both the chatbot (letting me upload the photo's) and tvbox (showing me all the uploaded photo's).

2. Photo's are downloaded correctly, video's are not. Noticed some errors in the log:

```
 2020-07-07 13:05:00,712 - videohandler - INFO - video received
2020-07-07 13:05:00,715 - telegram.utils.promise - ERROR - An uncaught error was raised while running the promise
Traceback (most recent call last):
  File "/usr/local/lib/python3.7/dist-packages/telegram/utils/promise.py", line 56, in run
    self._result = self.pooled_function(*self.args, **self.kwargs)
  File "/home/pi/familiekiosk/src/videohandler.py", line 109, in on_video_received
    if update and update.message:
AttributeError: 'CallbackContext' object has no attribute 'message'
```

3. Forward button works, previous doesn't. Checked the wires and there shouldn't be anything wrong with it, both reply and previous button are connected the same way. Might check with a different wire (can I look for the problem with a multitool?)

4. Reply button crashes TVbox but this might be due to the fact that chatbot wasn't running. However, when starting chatbot the following error keeps repeating:
```
Traceback (most recent call last):
  File "/usr/local/lib/python3.7/dist-packages/telegram/ext/jobqueue.py", line 418, in tick
    job.run(self._dispatcher)
  File "/usr/local/lib/python3.7/dist-packages/telegram/ext/jobqueue.py", line 574, in run
    self.callback(CallbackContext.from_job(self, dispatcher))
  File "/home/pi/familiekiosk/src/replyhandler.py", line 75, in do_reply
    bot.send_message(chat_id=chat_id, text=msg_text)
NameError: name 'bot' is not defined
```

Sn1ckerson, 2020-09-29:
Bump!
I had a friend of mine look at the code and apperantly there's something wrong with the bootsequence.
First of all the FK_chatbot and TVbox wouldn't automatically start up because in `os.path.isfile("config.py"):` he didn't look in the SRC folder. If i recall correctly my friend fixed this by first making him look for the path, add that to a variable "Path" and using that variable instead.
This fixed it, the code is able to find the config file but after a restart there's still nothing on the screen.
My friend went searching for the problem again and told me that the script is running before the screen is recognised which results in an error.

bmcage, 2020-10-29:
Boot sequence order changing over different releases is unfortunately a common problem.
Perhaps try the trick of custom target: https://www.mauras.ch/systemd-run-it-last.html
Otherwise try with graphical.target. https://unix.stackexchange.com/questions/506347/why-do-most-systemd-examples-contain-wantedby-multi-user-target
I still did not rebuild with latest raspbian, can only give more info after I find time to do that.

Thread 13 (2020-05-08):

familiekiosk on python 3.7

janvangent, 2020-05-08:
The familiekiosk doesn't seem to be working anymore on a clean install with raspbian strecht or buster (tried both). This is the case for when running both python 2.7 or 3.7 by the way.

In an attempt to get it up& running again, it probably makes sense to start with Raspbian buster and python 3.7 (to be up to date).

First remark: all instances of ConfigParser should be changed to configparser in FK_Chatbot.py
Without this change the service won't even start.

Once this is done, and the service is up and running, I get these errors when sending a picture through telegram:
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

There is also an issue with FK_tvbox.py. When this service is started upon boot, it throws an error:
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
If started manually, it does seem to work

I believe there is quite some rework to be done to get it up and running on new installs... But i'm lacking experience to get this done.

bmcage, 2020-05-08:
Ok, the service FK_tvbox.py needs to start after display is present. That seems to be no longer the case, so a matter of finding the correct time to launch it.

The error in chatbox is strange, as it is in a default library.
To test, add `.encode()` to strftime output.
Eg change on
https://github.com/TeamScheire/familiekiosk/blob/master/src/picturehandler.py#L55

    message.date.strftime('%Y-%m-%d %H:%M:%S')

into

    message.date.strftime('%Y-%m-%d %H:%M:%S').encode()

Search on other strftime to do the same. Test in python 3.7:

    >>> import datatime as dt
    >>> test = dt.datetime.now().strftime('%Y-%m-%d %H:%M:%S')
    >>> test
    '2020-05-08 15:31:38'
    >>> type(test)
    <class 'str'>
    >>> test2 = test.encode()
    >>> type(test2)
    <class 'bytes'>

bmcage, 2020-05-08:
For the service error, I see buster uses wayland, not xorg https://www.debian.org/releases/stable/amd64/release-notes/ch-information.en.html#apps-in-gnome-on-wayland

We are assuming xorg stuff: https://github.com/TeamScheire/familiekiosk/blob/master/systemd/fk_tvbox.service#L7

Limited info at the moment what this means https://www.raspberrypi.org/documentation/linux/usage/systemd.md
Try with

```
[Unit]
 Description=Family Kiosk System
 After=multi-user.target
 After=graphical.target

[Service]
 Type=idle
 ExecStart=/usr/bin/python /home/pi/familiekiosk/src/FK_TVbox.py > /home/pi/familiekiosk/output_TVbox.log 2>&1
```
If not working, try adding back in in the Service section

    Environment="DISPLAY=:0"
    Environment="XAUTHORITY=/home/pi/.Xauthority"

janvangent, 2020-05-09:
I tried changing to add .encode, but without any luck.
When I want to test it as you suggest:
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

bmcage, 2020-05-10:
Ok, best if I try to fix these issues with an updated raspberry pi.

For the test, it is import datetime, not datatime, I copied a wrong line in my example.

ErwinP, 2020-05-11:
Hi all,

I just got FK_Chatbox and FK_TVbox, hopefully with all their dependencies, working on python 3.6 and python-telegram-bot v12.7 (fresh Rasbian install from ~3 months ago).

https://github.com/ErwinP/familiekiosk/commit/b6e45f8352aa1d739cd020c1e6b71191b4444a22
https://github.com/ErwinP/familiekiosk/commit/5d365a6cee01674a997e4608585ff8f041aa357c

The latest comment of Jan is fixed by opening the metafile in "w" mode, instead of "wb" mode. The b stands for bytes, whilst it indeed does try to write out strings.

I did this on a headless Raspberry Pi setup, which is not supposed to run Familiekiosk. Hence, I haven't checked how it behaves when started as a service on boot, nor how it reacts on button presses. I can report that when FK_Chatbox and FK_TVbox running, my chatbot is responsive, parses images and displays them on the screen (tested by porting the X-display over ssh).

Hope this helps!
Erwin

Sn1ckerson, 2020-05-18:
Hi all,
Beginner programmer here.
I receive the same error messages even when started up manually (after running "systemctl status fk_chatbot.service").
I was trying to implement the fix bmcage suggested and pressed the run button in FK_chatbot.py (just for fun) which gave me the following error:
-----
Traceback (most recent call last):
  File "/home/pi/familiekiosk/src/FK_ChatBot.py", line 30, in <module>
    from telegram.ext import (Updater, CommandHandler, MessageHandler, Filters, Job, BaseFilter)
ModuleNotFoundError: No module named 'telegram'
-----
I followed all the steps as explained in the manual but it seems that I don't have telegram installed? Is this an error because of the way I ran the file or did I miss something?
I thought the command `telegram python API: `sudo pip install python-telegram-bot --upgrade`` would install this?

ErwinP, 2020-05-18:
Hi,

Indeed, that command should have installed it. Can you provide us with the output of `$ python -m telegram` , to double check if it has been installed?

Secondly, which python version are you on? You can check that with `$ python --version`.

Regards,
Erwin

bmcage, 2020-05-19:
@ErwinP Can you do a pull request for changing wb in w where needed? I would drop the python2 support, almost end of life

bmcage, 2020-05-19:
@ErwinP I see you have it in your PR in #7
I'll comment there

bmcage, 2020-05-20:
fixed with merge of #7

Closed 2020-05-20.

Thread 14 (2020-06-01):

Updating Python not mentioned

Sn1ckerson, 2020-06-01:
Hi
Can the manual add a couple of lines on how to upgrade Python?

I'm pretty new to Raspberry pi, Github etc and after a failed attempt at this project last year, I recently picked it up again. I redid all the steps as mentioned in the manual but still had a lot of errors (f.e. Telegram wasn't found).
Posted this in a previous issue and they mentioned to check my python version. Although I used the latest files from the raspberry website it was 2.7?
Did some googling and got it upgraded to 3.7 and redoing all the steps again (from a clean flash). Hope it will work!

bmcage, 2020-06-14:
Normally, latest raspbian is standard python3, at least it seemed like that on my last install. I need to retest familiekiosk however to know what exactly needs to change in the manual.

To change python version over the default one: https://raspberry-valley.azurewebsites.net/Python-Default-Version/#switching-default-python-versions

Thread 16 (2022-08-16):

gstreamer update broke this?

ErwinP, 2022-08-16:
Hi,

Somewhere an update broke FK_TVbox.py:

```
Traceback (most recent call last):
  File "FK_TVbox.py", line 851, in <module>
    app = TVbox()
  File "FK_TVbox.py", line 177, in __init__
    Gst.init(None)
  File "<string>", line 5, in init
TypeError: object of type 'NoneType' has no len()
```

I believe that the problem is in a version of gstreamer, as it doesn't print any plugins after importing them:
```import pgi
pgi.require_version('Gst', '1.0')      # install with: sudo apt-get install python-gst-1.0 gstreamer1.0-tools
pgi.require_version('GstVideo', '1.0')
pgi.require_version('GdkX11', '3.0')
from pgi.repository import Gst, GObject, GdkX11, GstVideo

reg = Gst.Registry.get()
for x in reg.get_plugin_list():
    print(x.get_name(), x.get_filename())
```
 --> this just results in an empty list.

Is there anybody that still has a working environment, and is willing to share there pip environment in the form of a requirements.txt, or tell me which version of gstreamer they are using, or wathever the dependency is that I'm missing?

The reason why I think it is due to an update of gstreamer, is because of the following commit:
https://github.com/TeamScheire/familiekiosk/commit/9f741cfc6c00a8914bf86f7efd69f089d9261b0f

Thank you in advance!
Erwin

bmcage, 2022-08-18:
On a working RPi, this is also an empty list for me if I do what you do.
If I first do Gst.init(None), and then repeat it, I obtain all plugins. So first init is needed, which crashes on your box....

The gstreamer installed is occording to the doc:
sudo apt-get install python-gst-1.0 gstreamer1.0-tools
which is a python2 package. So I assume
pgi.require_version('Gst', '1.0')
is not using that version in reality, but a version installed by default in RPi? Can't find any other Gst.py on my RPi however.
I'll update this box, but is older RPi.

bmcage, 2022-08-18:
After dist-upgrade on my 2020 RPi, all still works. After some digging, I believe the actual gstreamer plugin lives in
/usr/lib/arm-linux-gnueabihf/girepository-1.0

Following standard packages are then used, no pip:
gir1.2-gst-plugins-base-1.0
gir1.2-polkit-1.0
gpicview
gstreamer1.0-alsa
gstreamer1.0-libav
gstreamer1.0-plugins-bad
gstreamer1.0-plugins-base
gstreamer1.0-plugins-good
gstreamer1.0-x

ErwinP, 2022-08-23:
Thanks for the help, and replying even to a project as old as this one!

In the end, I started messing up my Python environment and just did a clean install of raspbian. Gstreamer still wasn't working for Python 3, but apparently gst for Python3 has been renamed ([thank you!](https://github.com/TaylorSMarks/playsound/issues/16#issuecomment-658182306)):
`sudo apt-get install python3-gst-1.0` instead of `sudo apt-get install python-gst-1.0`.

Going to do some more testing, but it seems to be working. I'm going to create a pull request, just for all completeness :)

Stupid how much time I lost because of this, dammit :p

Closed 2022-08-23.

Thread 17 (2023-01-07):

Latest Python-Telegram-Bot API update

janvangent, 2023-01-07:
PTB (Python Telegram Bot) has gone through quite some changes recently.
In December 2022, PTB went from version 13.15 to 20.X, and there are quite a lot of changes so it appears.
Some of these seem to impact the familiekiosk... I currently don't have the time to dig into it, and try to fix the code to make it work for 20.X, so I took the quick & dirty route instead: downgraded to 13.15 by using the following command:
sudo pip install python-telegram-bot==13.15

In case someone would find the time to work on an update of the familiekiosk code, so it can deal with 20.X, here is a transition guide:
https://github.com/python-telegram-bot/python-telegram-bot/wiki/Transition-guide-to-Version-20.0

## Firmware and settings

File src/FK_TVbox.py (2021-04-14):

#!/usr/bin/env python
# -*- coding: utf-8 -*-

from __future__ import division, print_function

import os
import sys

import pexpect   # sudo apt-get install python-pexpect

if os.path.isfile("config.py"):
    from config import *
else:
    print("No valid config file found - did you rename config.py.in to config.py?")
    sys.stdout.flush()
    print("Exiting...")
    sys.exit()

HAS_BUTTON = REPLY_BUTTON or NEXT_BUTTON or PREV_BUTTON
HAS_GPIO = HAS_BUTTON or BUZZER_PRESENT

STATE_PIC = 0
STATE_VID = 1
STATE_AUD = 2

TEST_RECENT_MODE =  False # if true, always in alarm mode
TEST_VID = False # show video's to test if video playback works

if sys.version_info[0] == 2:  # the tkinter library changed it's name from Python 2 to 3.
    import Tkinter
    tkinter = Tkinter #I decided to use a library reference to avoid potential naming conflicts with people's programs.
else:
    import tkinter
    Tkinter = tkinter

import threading

if sys.version_info[0] == 2:  # the configparser library changed it's name from Python 2 to 3.
    import ConfigParser
    configparser = ConfigParser
else:
    import configparser
    ConfigParser = configparser

from PIL import Image, ImageTk, ImageEnhance, ImageFilter  
import functools
import time
from datetime import datetime

# you need: https://pypi.org/project/RPi.GPIO/ 
# install via: sudo apt-get install python-rpi.gpio python3-rpi.gpio
if HAS_GPIO:
    import RPi.GPIO as GPIO

import glob

import gi
gi.require_version('Gst', '1.0')      # install with: sudo apt-get install python-gst-1.0 gstreamer1.0-tools
gi.require_version('GstVideo', '1.0')
gi.require_version('GdkX11', '3.0')
from gi.repository import Gst, GObject, GdkX11, GstVideo

import random
from random import shuffle

#BASE_PATH_LOG =  os.path.abspath(os.path.dirname(sys.argv[0])) + '/../tv_box.log'
#sys.stdout = open("tv_box.log", "w+")

BASE_PIC_PATH = os.path.abspath(os.path.dirname(sys.argv[0])) + '/pics/'
IMAGES = os.path.join(BASE_PIC_PATH, '*.jpg')

BASE_VID_PATH = os.path.abspath(os.path.dirname(sys.argv[0])) + '/video/'
VIDEOS = os.path.join(BASE_VID_PATH, '*.mp4')

BASE_AUD_PATH = os.path.abspath(os.path.dirname(sys.argv[0])) + '/voice/'
VOICES = os.path.join(BASE_AUD_PATH, '*.ogg')

testvid = BASE_VID_PATH + "/dummy/testvideo.mp4"
testaud = BASE_AUD_PATH + "/dummy/testvoice.ogg"


class TVbox():
        
    def __init__(self):
        self.state = STATE_PIC
        self.change_state = False
        self.timeticks = 200
        self.timeslept = 0
        
        self.currentimage = -1
        self.currentvideo = -1
        self.currentaudio = -1
        self.showimagenr = 0
        self.showvideonr = 0
        self.showaudionr = 0
        self.len_img_list = 0
        self.new_images = -2
        self.first_photo_already_shown = 0
        self.len_vid_list = 0
        self.len_aud_list = 0
        self.list_of_img = []
        self.list_of_vid = []
        self.list_of_aud = []
        self.playduration = 10
        self.timeshowstart = time.time()
        self.replybtnpressed = False
        self.nextbtnpressed = False
        self.prevbtnpressed = False
        self.stopplayingvideo = False
        self.stopplayingaudio = False
        self.ext_process = None
        
        self.root = tkinter.Tk()
        #self.root.attributes('-fullscreen', True)
        #set no border
        self.root.config(highlightthickness=0, cursor='none')
        self.label = tkinter.Label(text="Foto van ...", font=("Courier", 44))
        if DISPLAY_BANNER:
            self.label.pack(fill=tkinter.X)
        
        self.w, self.h = self.root.winfo_screenwidth(), self.root.winfo_screenheight()
        self.root.bind('<Escape>', self.closefullscreen)
        self.root.bind('<Return>', self.closefullscreen)
        self.root.bind("<ButtonPress-1>", self.closefullscreen)
        self.root.bind("<ButtonPress-2>", self.test_prev)
        self.root.bind("<ButtonPress-3>", self.test_next)
        self.root.overrideredirect(True)
        # no window decoration to close the window! 
        self.root.geometry("%dx%d+0+0" % (self.w, self.h))
        self.root.resizable(False, False)
        self.root.update_idletasks()
        self.root.focus_set()
        
        #update Tk to be able to querry label size
        self.root.update()
        self.w_label, self.h_label = self.label.winfo_width(), self.label.winfo_height()
        
        # add a canvas
        self.canvas = tkinter.Canvas(self.root, width=self.w, height=self.h-self.h_label, bg="black",
                                     highlightthickness=0)
        #canvas.configure(background='black')
        #canvas.bind("<Escape>", closefullscreen)
        #canvas.bind("<Return>", closefullscreen)
        self.canvas.bind("<ButtonPress-1>", self.closefullscreen)
        self.canvas.bind("<ButtonPress-2>", self.test_prev)
        self.canvas.bind("<ButtonPress-3>", self.test_next)
        
        # set up the reply button
        if HAS_GPIO:
            GPIO.setmode(GPIO.BCM)
        if REPLY_BUTTON:
            #use pin 18 to query the pushbutton
            GPIO.setup(REPLY_PIN, GPIO.IN, pull_up_down=GPIO.PUD_UP)
        if NEXT_BUTTON:
            #use pin 18 to query the pushbutton
            GPIO.setup(NEXT_PIN, GPIO.IN, pull_up_down=GPIO.PUD_UP)
        if PREV_BUTTON:
            #use pin 23 to query the pushbutton
            GPIO.setup(PREV_PIN, GPIO.IN, pull_up_down=GPIO.PUD_UP)
        if BUZZER_PRESENT:
            GPIO.setup(BUZZER_PIN, GPIO.OUT)

        self.canvas.pack()
        
        # add gstreamer now in it's own canvas
        
        #GObject.threads_init()
        Gst.init(None)
        
        # you can also use display_frame = tkinter.Frame(window)
        self.display_frame = tkinter.Canvas(self.root, width=self.w, height=self.h-self.h_label,
                                            bg="black", highlightthickness=0)
        self.display_frame.bind("<ButtonPress-1>", self.closefullscreen)
        self.display_frame.bind("<ButtonPress-2>", self.test_prev)
        self.display_frame.bind("<ButtonPress-3>", self.test_next)
        self.display_frame.pack(side=tkinter.TOP, expand=tkinter.YES, fill=tkinter.BOTH)
        self.frame_id = self.display_frame.winfo_id()

        self.listimages()
        self.listvideos()
        self.listvoices()
        
        if (TEST_VID):
            self.state = STATE_VID
            self.change_state = True

        self.show()
        
        #start with pics only     
        #self.hide_vid()
        
        self.update_app()
        
        self.root.mainloop()


    def set_frame_handle(self, bus, message):
        if not message.get_structure() is None:
            #print (message.get_structure().get_name())
            if message.get_structure().get_name() == 'prepare-window-handle':
                display_frame = message.src
                display_frame.set_property('force-aspect-ratio', True)
                display_frame.set_window_handle(self.frame_id)

    def show_pic(self):
        self.canvas.pack()
    
    def hide_pic(self):
        self.canvas.pack_forget()
        
    def show_vid(self):
        self.display_frame.pack(side=tkinter.TOP, expand=tkinter.YES, fill=tkinter.BOTH)
        self.frame_id = self.display_frame.winfo_id()    
        
    def hide_vid(self):
        self.display_frame.pack_forget()

    def set_video(self, path):
        filepath = os.path.realpath(path)
        filepath2 = "file:///" + filepath.replace('\\', '/').replace(':', '|')
        self.player.set_property('uri', filepath2)

    def most_recent_mode(self):
        """
        In recent mode or not? recent mode is from Alarm to Alarm + 30 min
        """
        if (TEST_RECENT_MODE or TEST_VID): return True
        #30 min after alarm time only recent images
        now = datetime.now()
        limit_min_start = ALARM_HOUR * 60 + ALARM_MIN
        limit_min_end = limit_min_start + 30
        now_min = now.hour *60 + now.minute
        #print (limit_min_start, now_min, limit_min_end)
        # limit pics if needed
        if limit_min_start <= now_min <= limit_min_end:
            return True
        return False

    def listimages(self):
        """
        Obtain a list of images to allow reaction
        30 min after alarm time: only the recent images
        otherwise all images
        """
        list_of_files = sorted(glob.iglob(IMAGES), key=os.path.getmtime, reverse=True)

    
        list_of_files = [x for x in list_of_files if x[-9:] != "_comp.jpg"]
        if self.len_img_list != len(list_of_files) and self.new_images != -2 :
            #New images have arived, show the first ones as determined in the config
            print("Showing the newly-arrived images")
            sys.stdout.flush()
            self.new_images =  len(list_of_files) - self.len_img_list
            self.list_of_img = list_of_files
            if self.first_photo_already_shown == 0 :
                print("Reset showimagenr only the first time we're in this loop of new photo's")
                sys.stdout.flush()
                self.showimagenr = 0
                self.first_photo_already_shown = 1
            if self.new_images == self.showimagenr or self.showimagenr == MAX_JPG :
                #When all new images have been shown or if we're at the maximum, 
                #get out of this condition and prepair to detect for a new load
                print("all new images have been shown")
                sys.stdout.flush()
                self.len_img_list = len(list_of_files)
                self.new_images = -1 
                self.first_photo_already_shown = 0
        elif self.new_images == -2 :
            #if here, it's because the pi was booted for the first time
            print ("Detected the first boot")
            sys.stdout.flush()
            self.list_of_img = list_of_files
            self.len_img_list = len(list_of_files)

        if self.most_recent_mode():
            #print (self.most_recent_mode)
            print ("we're in recent mode")
            sys.stdout.flush()
            self.list_of_img = list_of_files[:MAX_JPG]
        elif (RANDOMIZE_PHOTOS == True) :
            #do not rebuild the list of images while in random mode
            print ("not rebuilding the list while in random mode to prevent re-randomization")
            sys.stdout.flush()
            self.list_of_img =  self.list_of_img
        else:
            self.list_of_img = list_of_files
            print ("not in recent mode and not in random mode - use the  sorted list")
        #print (self.list_of_img)
        #sys.stdout.flush()

    def listvideos(self):
        """
        Obtain a list of videos to allow reaction
        30 min after alarm time: only the recent videos
        otherwise all videos
        """
        list_of_files = sorted( glob.iglob(VIDEOS), key=os.path.getmtime, reverse=True)
    
        if self.len_vid_list != len(list_of_files):
            #new video arrived, show it
            self.showvideonr = 0
        self.len_vid_list = len(list_of_files)
        
        if self.most_recent_mode():
            self.list_of_vid = list_of_files[:MAX_VID]
        else:
            self.list_of_vid = list_of_files

    def listvoices(self):
        """
        Obtain a list of voice messages to allow reaction
        30 min after alarm time: only the recent videos
        otherwise all videos
        """
        list_of_files = sorted( glob.iglob(VOICES), key=os.path.getmtime, reverse=True)
    
        if self.len_aud_list != len(list_of_files):
            #new video arrived, show it
            self.showaudionr = 0
        self.len_aud_list = len(list_of_files)
        
        if self.most_recent_mode():
            self.list_of_aud = list_of_files[:MAX_AUD]
        else:
            self.list_of_aud = list_of_files

    def show(self):
        """ update what we show """
        # first stop playing something if needed
        if self.stopplayingaudio or (self.stopplayingvideo and not USE_EXTERNAL_VIDEO_PLAYER):
            #stop gstreamer
            if hasattr(self, 'player'):
                print ('STOPPING the current playing track on gstreamer')
                self.player.set_state(Gst.State.READY)
                self.player.set_state(Gst.State.NULL)
                del self.bus
                del self.player
        elif self.stopplayingvideo and USE_EXTERNAL_VIDEO_PLAYER:
            # we need to kill the subprocess running the external vid ...
            if self.ext_process:
                #self.ext_process.kill()
                # to kill omxplayer only sending CTRL-C seems to work:
                self.ext_process.sendcontrol('c')
                self.ext_process.close()
                time.sleep(0.2)
                self.ext_process = None
            
        if not self.most_recent_mode():
            #we should only show pictures! 
            if self.state != STATE_PIC:
                self.state = STATE_PIC
                self.change_state = False
                self.hide_vid()
                self.show_pic()
        
        #depending on state, we show pic, video or voice
        if self.state == STATE_PIC:
            self.showimage()
        elif self.state == STATE_VID:
            self.showvideo()
        elif self.state == STATE_AUD:
            self.showvoice()
                            
    def showimage(self):
        if self.currentimage != self.showimagenr:
            # we regenerate list of images to have latest present
            self.listimages()
            # Only consider shuffling if there are no new images to be shown
            if self.showimagenr  > self.new_images and self.new_images < 0 and RANDOMIZE_PHOTOS == True : 
                 shuffle(self.list_of_img)
                 self.new_images = 0
                 self.showimagenr = 0
                 print ("Shuffled the list, new_images is now ", self.new_images)
                 sys.stdout.flush()
            # now show the next image
            if len(self.list_of_img) == 0 :
                #no images yet, show dummy
                self.showPIL(os.path.join(BASE_PIC_PATH, 'dummy', 'dummy.jpg'))
                meta_filename = None
            else:
                self.showimagenr = self.showimagenr % len(self.list_of_img)
                self.showPIL(self.list_of_img[self.showimagenr])
                meta_filename = self.list_of_img[self.showimagenr] + '_meta.cfg'
            self.timeshowstart = time.time()
            self.currentimage = self.showimagenr
            #obtain meta information if present
            if meta_filename and os.path.isfile(meta_filename):
                config = ConfigParser.RawConfigParser()
                config.read(meta_filename)
                self.img_user = "{} {}".format(config.get("user", "first_name"),
                                           config.get("user", "last_name"))
                self.img_day = config.get("message", "day")
            else:
                self.img_user = ''
                self.img_day = ''

    def showPIL(self, image_file):
        Pic = Image.open(image_file)
        pilImage = self.image_transpose_exif(Pic)
        #pilImage.save(os.path.join(BASE_PIC_PATH,"transformed.jpg"))
        imgWidth, imgHeight = pilImage.size
        print ('SHOWING', image_file, imgWidth, imgHeight, self.w, self.h-self.h_label)
        sys.stdout.flush()

        # Generate the background
        if imgWidth < self.w : # Our image is smaller then the screen
           imgRatio = imgWidth / imgHeight # Keep the original image ratio
           BackgroundImgWidth = int(self.w * 1.5) # Blow that photo up, nicer effect
           BackgroundImgHeight = int((BackgroundImgWidth / imgRatio))
           pilBackgroundImage = pilImage.resize((BackgroundImgWidth, BackgroundImgHeight), Image.ANTIALIAS)  

        elif imgHeight < self.h: 
           imgRatio = imgWidth / imgHeight 
           BackgroundImgHeight = int(self.h * 1.5)
           BackgroundImgWidth = int(imgRatio * BackgroundImgHeight)
           pilBackgroundImage = pilImage.resize((BackgroundImgWidth, BackgroundImgHeight), Image.ANTIALIAS)

        else:
           # The photo is equal or bigger than the screen, so scale it to that screen
           
           imgRatio = imgWidth / imgHeight
           BackgroundImgWidth = int(self.w * 1.5) # Blow that photo up, nicer effect
           BackgroundImgHeight = int((BackgroundImgWidth / imgRatio))

           if BackgroundImgHeight < self.h: # We scaled using the wrong parameter
              BackgroundImgHeight = int(self.h * 1.5)
              BackgroundImgWidth = int(imgRatio * BackgroundImgHeight)

           pilBackgroundImage = pilImage.resize((BackgroundImgWidth, BackgroundImgHeight), Image.ANTIALIAS)
           
        print("Backround_w, h:", BackgroundImgWidth, BackgroundImgHeight)
        sys.stdout.flush()

        # Blur and darken the background photo
        pilBackgroundImage = pilBackgroundImage.filter(ImageFilter.GaussianBlur(radius = 5))
        enhancer = ImageEnhance.Brightness(pilBackgroundImage)
        pilBackgroundImage = enhancer.enhance(0.5) # lower than 1 darkens the image

        # Generate the true in-focus picture 
        # too large or too small, scale to fit the frame
        ratio = min(self.w/imgWidth, (self.h-self.h_label)/imgHeight)
        imgWidth = int(imgWidth*ratio)
        imgHeight = int(imgHeight*ratio)
        pilForgroundImage = pilImage.resize((imgWidth, imgHeight), Image.ANTIALIAS)

        # Paste the Forground on top of the background
        # test:
        # pilImage = pilBackgroundImage
        offset = ((BackgroundImgWidth - imgWidth) // 2, (BackgroundImgHeight - imgHeight) // 2)
        pilBackgroundImage.paste(pilForgroundImage, offset)
        
        pilImage = pilBackgroundImage
        self.image = ImageTk.PhotoImage(pilImage)
        imagesprite = self.canvas.create_image(self.w/2, 
                                               (self.h-self.h_label)/2, 
                                               image=self.image)

    def image_transpose_exif(self, im):
        """
            Apply Image.transpose to ensure 0th row of pixels is at the visual
            top of the image, and 0th column is the visual left-hand side.
            Return the original image if unable to determine the orientation.
            As per CIPA DC-008-2012, the orientation field contains an integer,
            1 through 8. Other values are reserved.
            Thanks to Roman Odaisky and others:
            https://stackoverflow.com/questions/4228530/pil-thumbnail-is-rotating-my-image/
        """
        exif_orientation_tag = 0x0112
        exif_transpose_sequences = [                   # Val  0th row  0th col
            [],                                        #  0    (reserved)
            [],                                        #  1   top      left
            [Image.FLIP_LEFT_RIGHT],                   #  2   top      right
            [Image.ROTATE_180],                        #  3   bottom   right
            [Image.FLIP_TOP_BOTTOM],                   #  4   bottom   left
            [Image.FLIP_LEFT_RIGHT, Image.ROTATE_90],  #  5   left     top
            [Image.ROTATE_270],                        #  6   right    top
            [Image.FLIP_TOP_BOTTOM, Image.ROTATE_90],  #  7   right    bottom
            [Image.ROTATE_90],                         #  8   left     bottom
        ]

        try:
            seq = exif_transpose_sequences[im._getexif()[exif_orientation_tag]]
        except Exception:
            return im
        else:
            print("Succesfully read exif data")
            sys.stdout.flush()
            return functools.reduce(type(im).transpose, seq, im)


    def showvideo(self):
        if self.currentvideo != self.showvideonr:
            # we regenerate list of vids to have latest present
            self.listvideos()
            # now show the next image
            if len(self.list_of_vid) == 0 :
                #no vid yet, ERROR ! 
                return

            self.showvideonr = self.showvideonr % len(self.list_of_vid)

            if USE_EXTERNAL_VIDEO_PLAYER:
                self.ext_process = pexpect.spawn('omxplayer ' +
                                        self.list_of_vid[self.showvideonr]) 
            else:
                #show video
                if hasattr(self, 'player'):
                    del self.bus
                    del self.player
                self.player = Gst.ElementFactory.make('playbin', None)
                self.bus = self.player.get_bus()
                self.bus.enable_sync_message_emission()
                self.bus.connect('sync-message::element', self.set_frame_handle)
                self.set_video(self.list_of_vid[self.showvideonr])
                self.player.set_state(Gst.State.PLAYING)

            self.timeshowstart = time.time()
            meta_filename = self.list_of_vid[self.showvideonr] + '_meta.cfg'
            self.currentvideo = self.showvideonr
            #obtain meta information if present
            if meta_filename and os.path.isfile(meta_filename):
                config = ConfigParser.RawConfigParser()
                config.read(meta_filename)
                self.img_user = "{} {}".format(config.get("user", "first_name"),
                                           config.get("user", "last_name"))
                self.img_day = config.get("message", "day")
                self.playduration = config.getfloat("message", "duration") + 5
            else:
                self.img_user = ''
                self.img_day = ''
                self.playduration = 10
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

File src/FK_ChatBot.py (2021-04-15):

#!/usr/bin/env python
# -*- coding: utf-8 -*-

"""Simple Bot to reply to Telegram messages.

This program is dedicated to the public domain under the CC0 license.

This Bot uses the Updater class to handle the bot.

First, a few handler functions are defined. Then, those functions are passed to
the Dispatcher and registered at their respective places.
Then, the bot is started and runs until we press Ctrl-C on the command line.

Usage:
Basic Echobot example, repeats messages.
Press Ctrl-C on the command line or send a signal to the process to stop the
bot.
"""

from __future__ import division, print_function

import sys, os.path, time

if sys.version_info[0] == 2:  # the configparser library changed it's name from Python 2 to 3.
    import ConfigParser
    configparser = ConfigParser
else:
    import configparser
    ConfigParser = configparser
    
import telegram
from telegram.ext import (Updater, CommandHandler, MessageHandler, Filters, Job, MessageFilter)
import logging

if os.path.isfile("config.py"):
    from config import *
else:
    print("No valid config file found - did you rename config.py.in to config.py?")
    sys.stdout.flush()
    print("Exiting...")
    sys.exit()


# Enable logging
logging.basicConfig(format='%(asctime)s - %(name)s - %(levelname)s - %(message)s',
                    level=logging.INFO)

logger = logging.getLogger(__name__)

import picturehandler
picturehandler.set_email(EMAIL_FRAME)
from replyhandler import do_reply
import voicehandler
import videohandler


ACCEPTED_CHATS = os.path.join(os.path.abspath(os.path.dirname(sys.argv[0])), 'chatlist.ini')
APPROVED_CHATS = []

# Define a few command handlers. These usually take the two arguments bot and
# update. Error handlers also receive the raised TelegramError object in error.
def start(update, context):
    """Send a message when the command /start is issued."""
    update.message.reply_text('Hallo, geef het wachtwoord in met commando \n/secret XXXXX\n (XXXX vervang je door het wachtwoord)')


def help(update, context):
    """Send a message when the command /help is issued."""
    update.message.reply_text('Help!')


def echo(update, context):
    """Echo the user message."""
    print ('tekst')
    sys.stdout.flush()
    update.message.reply_text(update.message.text)

def secret(update, context):
    """Give the secret to accept messages to this bot """
    global APPROVED_CHATS
    password = "".join(context.args)
    print ('Received pass', password)
    sys.stdout.flush()
    if password == PASSWORD:
        update.message.reply_text("Correct! Vanaf nu kan je foto's en video's sturen naar deze groep")
        #we voegen toe aan lijst van correcte chat
        chatid = update.message.chat.id
        print (chatid)
        sys.stdout.flush()
        
        if os.path.isfile(ACCEPTED_CHATS):
            config = ConfigParser.RawConfigParser()
            config.read(ACCEPTED_CHATS)
            try:
                chat_idtxt = config.get("Approved", "chatids")
            except:
                chat_idtxt = ""
            chat_ids = chat_idtxt.split(',')
            APPROVED_CHATS = [int(x) for x in chat_ids if x]
            if chatid and chatid not in APPROVED_CHATS:
                #add it to accepted chatids
                APPROVED_CHATS += [chatid]
                if not config.has_option("Approved", "chatids"):
                    config.add_section("Approved")
                config.set("Approved", "chatids",
                           ','.join([str(x) for x in APPROVED_CHATS]))
                with open(ACCEPTED_CHATS, 'w') as metafile:
                    config.write(metafile)
    else:
        update.message.reply_text("Fout wachtwoord!")
        
def not_authorized(update, context):
    update.message.reply_text('Je bent nog niet gekend, geef eerst het wachtwoord in met commando \n/secret XXXXX\n (XXXX vervang je door het wachtwoord)')

def error(bot, update):
    """Log Errors caused by Updates."""
    logger.warning('Update "%s" caused error "%s"', update, update.error)


class FilterApprovedChat(MessageFilter):
    def filter(self, message):
        return message.chat.id in APPROVED_CHATS

# Remember to initialize the class.
filter_approved_chats = FilterApprovedChat()

def main(disp=None):
    """Start the bot."""
    # Obtain approved chats
    global APPROVED_CHATS
    if os.path.isfile(ACCEPTED_CHATS):
        config = ConfigParser.RawConfigParser()
        config.read(ACCEPTED_CHATS)
        try:
            chat_idtxt = config.get("Approved", "chatids")
        except:
            chat_idtxt = ""
        chat_ids = chat_idtxt.split(',')
        APPROVED_CHATS = [int(x) for x in chat_ids if x]
            
    # Create the EventHandler and pass it your bot's token.
    if disp:
        updater = Updater(TOKEN, use_context=True, workers=None,
                          dispatcher=disp)
    else:
        updater = Updater(TOKEN, use_context=True)

    # Get the dispatcher to register handlers
    dp = updater.dispatcher

    if disp is None:
        # on different commands - answer in Telegram
        dp.add_handler(CommandHandler("start", start))
        dp.add_handler(CommandHandler("help", help))
        dp.add_handler(CommandHandler("secret", secret, pass_args=True))
        
        # For testing: on noncommand i.e message - echo the message on Telegram
        # dp.add_handler(MessageHandler(Filters.all, echo))

        # we react on receiving a picture
        dp.add_handler(MessageHandler(Filters.photo & filter_approved_chats, picturehandler.on_photo_received, run_async=True))
        # we react on receiving a voice message
        dp.add_handler(MessageHandler(Filters.voice & filter_approved_chats, voicehandler.on_voice_received, run_async=True))
        # we react on video message
        dp.add_handler(MessageHandler(Filters.video_note & filter_approved_chats, videohandler.on_video_note_received, run_async=True))
        dp.add_handler(MessageHandler(Filters.video & filter_approved_chats, videohandler.on_video_received, run_async=True))

        # catchall if not approved user
        dp.add_handler(MessageHandler(Filters.photo | Filters.voice | Filters.video_note | Filters.video, not_authorized))
    
    # Get the job queue to shedule jobs, see doc at
    # https://github.com/python-telegram-bot/python-telegram-bot/wiki/Extensions-%E2%80%93-JobQueue
    jq = updater.job_queue
    
    # scan if we need to reply from time to time (every 2 min)
    job_reply = jq.run_repeating(do_reply, interval=120, first=0)

    # log all errors
    dp.add_error_handler(error)
    
    return updater
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

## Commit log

2018-05-10 test met een eigen fotokader
2018-05-21 Raspberry Pi fotoframe based on Telegram received images
2018-05-21 bugfix, prepare to react on button
    [FK_TVbox.py, picturehandler.py]
2018-05-25 Correct scaling of images
    [FK_TVbox.py]
2018-05-28 Next button to see next picture implemented
2018-06-01 add a previous pic button
2018-06-01 on reply button press, store info so the chatbot can do the reply
2018-06-02 Do a reply when button is pressed
2018-06-02 bufixes in reply button handling
2018-06-02 test code for an output pin
2018-06-02 button should be 18
2018-06-02 add buzzer code for an alarm at 18.00
    [FK_TVbox.py]
2018-06-02 switch to limited #pic after alarm to again all pic
2018-06-05 on prev/next, stop current playing of gstreamer before going to prev/next
2018-06-05 bugfix: on rasp to kill player ctrl+c needed bugfix: only set state if there is a player
    [FK_TVbox.py]
2018-06-24 the lasercut box for the kiosk
2018-06-24 add link to lasercut box example
2018-06-24 final fixes to run
    [FK_TVbox.py]
2018-06-27 increase play time to avoid cutoff at end
    [FK_TVbox.py]
2018-11-10 bugfix: GND and VCC switched
2018-11-10 update on the lasercut box
2018-11-11 Image with pushbutton wiring
2018-11-11 Add wiring buttons
2018-11-11 use github sizing of images method for wiring img
2018-12-02 Update DIY Familiekiosk.md
    Getest met een nieuwe versie van raspbian en een aanwijzing toegevoegd over de testen met gst-launch-1.0 playbin.
2018-12-02 Hint om de terminal te vinden in raspbian
2018-12-02 Update DIY Familiekiosk
    Verduidelijking hoe een terminal opgestart kan worden
2018-12-02 Aanraden om browser in raspberry pi te gebruiken
    Gebruik van de browser in de raspberri pi zelf maakt het makkelijker om het token te kopiëren.
2019-01-23 kleine tekstuele aanpassingen + extra optie om witte balk bovenaan de kiosk aan- of uit te zetten.
2019-01-23 alternatieve box, met rechte hoeken
    [export-back.dxf, export-bottom.dxf, export-front.dxf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]
2019-04-11 Revert "Better implementation of shuffling the photo's"
    This reverts commit 3ea4c980734531d54e0d7043394d36d10235aaba.
    [FK_TVbox.py]
2019-04-11 Print the output to the system journal
    https://fhackts.wordpress.com/2014/11/27/systemd-journal-not-showing-python-3-print/
2019-04-11 Fix randomization, transpose rotated images and add usefull debugging in system journal
    [FK_TVbox.py]
2020-05-11 Fix Python2 ConfigParser <-> Python3 configparser
    [FK_ChatBot.py]
2020-05-11 Update Telegram API and metafile writer
    In the Telegram API v12 (which is, at time of writing, the latest available for the Raspberry Pi 3), context
    based callbacks got upgraded:
    https://github.com/python-telegram-bot/python-telegram-bot/wiki/Transition-guide-to-Version-12.0
    Furthermore, the metafile writer got updated to write the parameters as strings instead of bytes (i.e. "w" instead of "wb").
2020-05-15 Check if config file is present.
    As explained in the tutorial, config.py.in should be renamed to config.py. If a
    user failes to do this, the following error is raised:
    from config import *
    ModuleNotFoundError: No module named 'config'
    The deceptive nature of this errors description makes it quite difficult to troubleshoot
    at first sight - the module is there, it's the file we're lacking.
    [FK_ChatBot.py, FK_TVbox.py]
2020-10-31 Use a blown-up, blurred & darkened photo for background
    When the photo does not fit the screen, it gets recaled. Unless the photo has the same imgRatio as the screen, this
    results in black bars either at the left/right (when portrait) or above/below (landscape) of the photo. Although it
    does the trick, it looks kind of ugly.
    Here, the background is generated from the shown image. It gets blown up, blurred and darkened to put the emphasis
    still on the "true" picture, wich is the rescaled one. The result is nothing else but slick.
    Specific values for the blow-up, blurring and darkening, might need some tweaking.
    [FK_TVbox.py]
2020-10-31 Scale correctly when original is bigger than screen
    [FK_TVbox.py]
2021-04-14 threads_init no longer needed
    [FK_TVbox.py]
2021-04-14 BugFix: Filters should now derive from MessageFilter
    [FK_ChatBot.py]
2021-04-15 bugfixes: video receive, use new async, wait for network
    [FK_ChatBot.py, picturehandler.py, videohandler.py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]
